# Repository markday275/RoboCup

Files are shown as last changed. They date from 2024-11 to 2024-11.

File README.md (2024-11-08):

# RoboCup - Third Place 2024

Welcome to the RoboCup Project repository! This project was designed and competed in the annual RoboCup competition for University of Canterbury third Yr Mechatronics, securing a **third-place finish**. This repository aims to maintain a well-documented structure for future enhancements, iterations, and collaboration in autonomous robotics.

## Table of Contents
1. [Project Overview](#project-overview)
2. [CAD](#setup-instructions)
3. [Code Structure](#code-structure)
6. [License](#license)

---

### Project Overview
This project is built around a robot designed to compete in RoboCup. There are three reports within this git that outlines the Robot in detail CDR , DDR and Competition report. Recommended reading is the Competition report as it outlines what worked and did not work in the competition. 

The robot is controlled by a Teensy 4.0 microcontroller with an IO expansion board. The teensy has 40 pins but 24 in the given configuration. Having a IO expander allows for the additional IO to be plugged in and multiplexed to. It also allows for standard connector types, serial, digital, i2c etc.
The code is developed and built in VS code as a platformIO project. This allows for greater functionality as the code written is C++ not Arduino C++. 

### CAD 
The robot has been designed to maximise simplicity and reliability. 
It uses sensors to gather information from the world. From this information it moves throughout area to gather weights and returns them to base.
To do this the robot must have primary motion system, the system implemented is a ‘tank drive’ system. The robot has ToF sensors that return distances from walls and obstacles which allow it to navigate throughout the area. 
The robot uses ultrasound sensors to identify all weights, it then uses the navigation system to rotate and drive towards the weight. The weight is collected then is kept on board with a “sheep gate” system using an inductive proximity sensor and servo. The inductive proximity sensor determines if the weight is a target or dummy. The robot then continues forward searching for more weights until it holds 3 on board where it returns home. 

See CAD for solidworks parts and refer to assembly to complete design

### Code Structure

The robot is controlled by a Teensy 4.0 microcontroller with an IO expansion board. The teensy has 40 pins but 24 in the given configuration. Having a IO expander allows for the additional IO to be plugged in and multiplexed to. It also allows for standard connector types, serial, digital, i2c etc.
The code is developed and built in VS code as a platformIO project. This allows for greater functionality as the code written is C++ not Arduino C++. 

The code is broken up into modules:
-	main.cpp: task scheduler set up and run. 
-	finite_state_machine.cpp: all states and logic to switch between them.
-	return_to_base.cpp: calculates where home is, if home and return home.
-	weight_collection.cpp: detects weights and functions to pick weight up.
-	smartmove.cpp: moves the robot based on sensors, move while avoiding walls etc.
-	motors.cpp: call to set motor/actuators values. 
-	sensors.cpp: takes in data from sensors.

### License
This project is licensed under the MIT License. See LICENSE for more details.

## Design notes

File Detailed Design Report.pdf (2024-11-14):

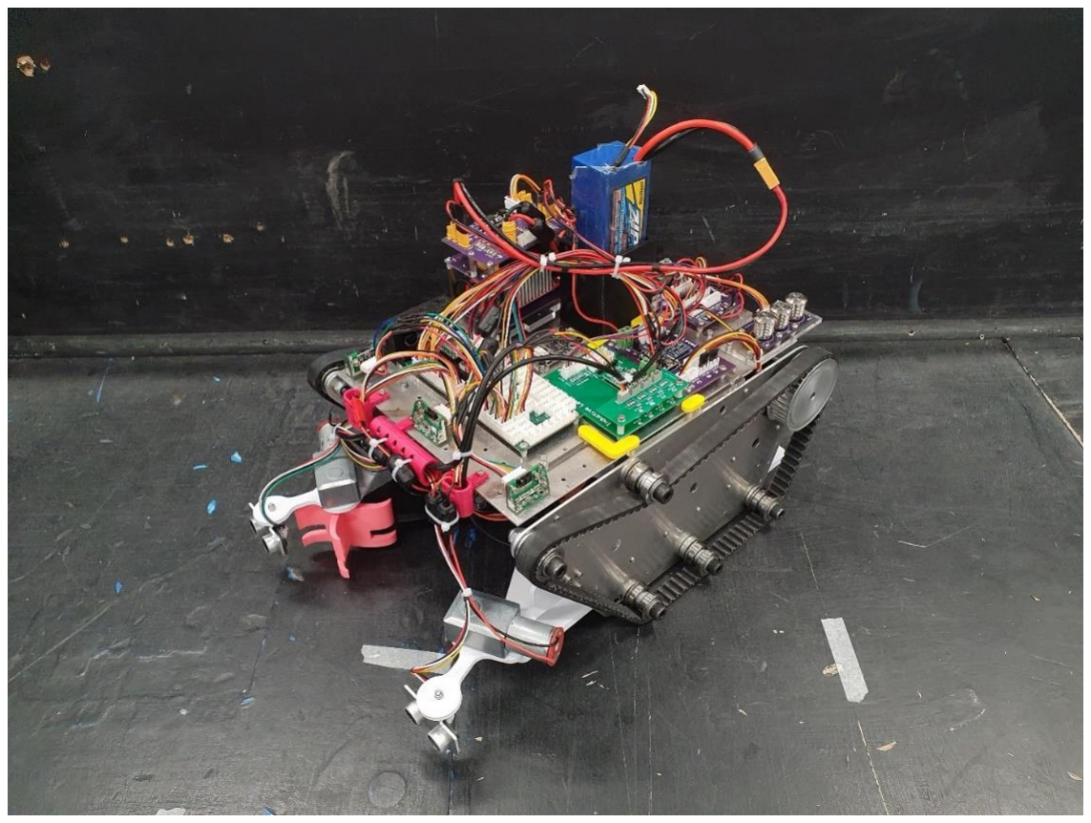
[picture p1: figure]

# Detailed Design Report

# ENMT301 09/09/24 Group 4

# Mark day

# Kieran James

# Jack Willson

i

## Executive Summary

To achieve desired outcomes the robot is divided into subsystem.

- Chassis and Drivetrain
- Target Detection
- Target Collection
- Navigation

The robot used a tank drive, drivetrain with the original gear. This fell short of the robot’s speed requirement 0.5 m/s. The actual speed achieved was 0.33 m/s. the chassis and drivetrain also produced a drift of -12%. Custom gears or software bias could improve speed and correct drift.

The target detection uses ToF and ultrasound sensors. A Boolean logic system detects targets and reduces noise with a moving average filter. This was tested using a best of 20 system by placing weights and recording the how successful the detection was. The target detection could be improved by consider replacing ultrasound sensors with more reliable ToF sensors.

The target collection uses a funnel and tray system that replaced the original combine harvester design. Weights are sorted based on material using an inductive proximity sensor and an IR sensor. The new tray system is reliable but does not meet the requirement for collecting weights in any orientation. Removing the combine motors could reduce weight and simplify the robot.

The robot navigation system works by detecting walls with ToF sensors and stores then position using odometry and gyro data. The system works inconsistently, with the robot failing to return home in three out of five runs. Additional ToF sensors and acceleration data from the IMU could enhance reliability.

An FTA was used to identify key components and likely causes of faults. From the FTA, Simplicity was prioritized to reduce risk, especially by replacing moving parts with static guides. The wiring was optimized for reliability, and code was modularized for flexibility. The gate was made from alloy to improve durability.

ii

## Table of Contents

## 1. Introduction

This report will detail the design and manufacturing of the RoboCup robot. It will detail each subsystem of the robot. Each subsystem will be assessed against the requirement set up in the conceptual design report (CDR). The subsystems will also be tested in a results section to improve the robot and recommendations made where the robot fails to meet the requirements.

The goal of the robot is to move out from home base into an area with obstacles and weights placed throughout. The robot must collect weights and bring them home to score points. The area layout is unknown, and the robot must not have any communication from the user. This makes the task difficult. To achieve this the following subsystems have been implemented

- Chassis and Drivetrain
- Target Detection
- Target Collection
- Navigation

The robot target collection has been changed from the CDR. This was due to reliability issues. The detail of the change is explained in section 2.2.

## 2. Design Description

## 2.1 Overview

The robot has been designed to maximise simplicity and reliability. The current robot is shown in Figure 1.

It uses sensors to gather information from the world. From this information it moves throughout area to gather weights and returns them to base.

To do this the robot must have primary motion system, the system implemented is a ‘tank drive’ system. The robot has ToF sensors that return distances from walls and obstacles which allow it to navigate throughout the area.

The robot uses ultrasound sensors to identify all weights, it then uses the navigation system to rotate and drive towards the weight. The weight is collected then is kept on board with a “sheep gate” system using an inductive proximity sensor and servo. The inductive proximity sensor determines if the weight is a target or dummy. The robot then continues forward searching for more weights until it holds 3 on board where it returns home.

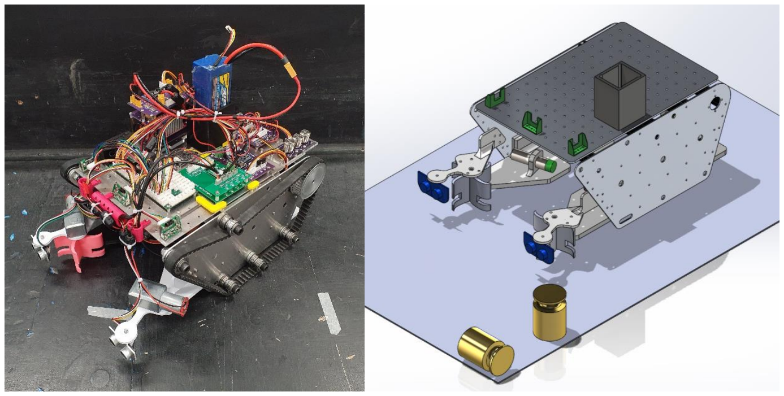
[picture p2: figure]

Figure 1: Group Four’s robot as of 08/09/24 (Left), CAD model (Right).

## 2.2 Chassis and Drivetrain

The chassis and drivetrain designs were taken from the CDR and used with minor modifications. The default chassis plates were used along with the standard configuration of tracks and bearings for the drivetrain (Figure 2) rather than printing new track sprockets as described in the CDR. The decision to use the standard sprocket was based on the fact the robot travelled at the desired speed with the alloy sprocket. The motors powering the tracks were 2x 28PA51G DC geared motors with built-in encoders. The motors were powered using a 2-channel DC motor driver and a PWM input. The extrusions were arranged to give the chassis sufficient stiffness and strength while allowing enough space at the front of the robot for the required weight collection components (Figure 3). Using the default chassis plates and extrusions also provided a significant amount of flexibility that was later found useful as the collection mechanism went through multiple further optimisations.

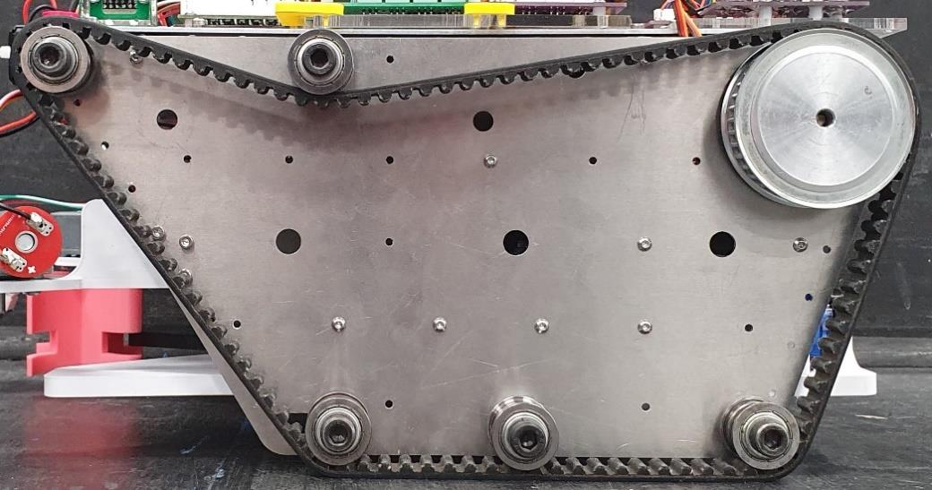
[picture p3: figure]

Figure 2: Chassis plate and drivetrain layout.

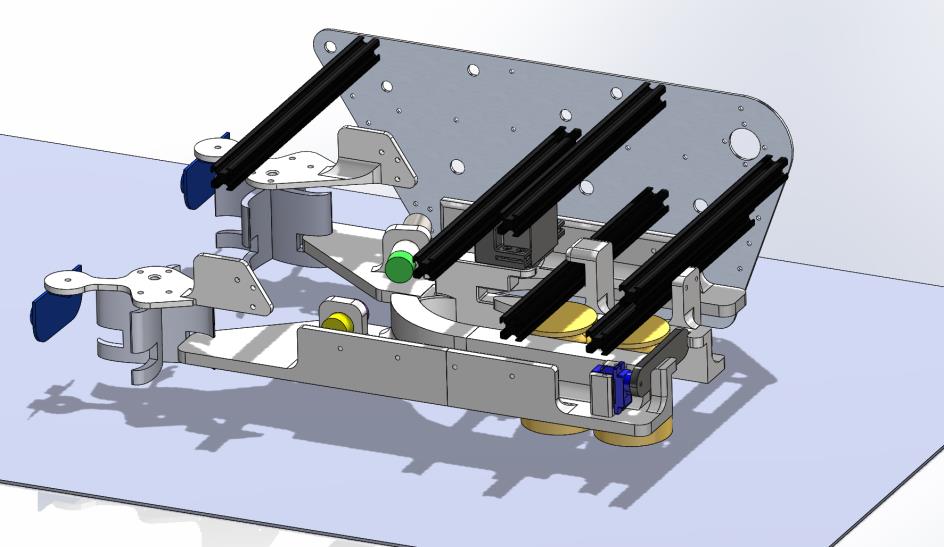
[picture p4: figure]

Figure 3: Arrangement of aluminium extrusions.

For mounting the electronics, the provided drilled plate was mounted to extrusions on the topside of the robot. This provided adequate space required for most of the supporting electrical circuits, the Teensy MCU and the battery (Figure 4). To fit some of the circuit boards, small brackets were printed as not all the boards had their own mounting holes. This made the electrical board more compact and discarded the need for a second mounting plate. The ultrasonic driver board and the second DC motor driver were attached to the underside of the electrical board for cable management and space. To help keep cables tidy, manageable and away from moving parts, cable organisers were printed and attached to the front. These also doubled as mounting points for cable ties.

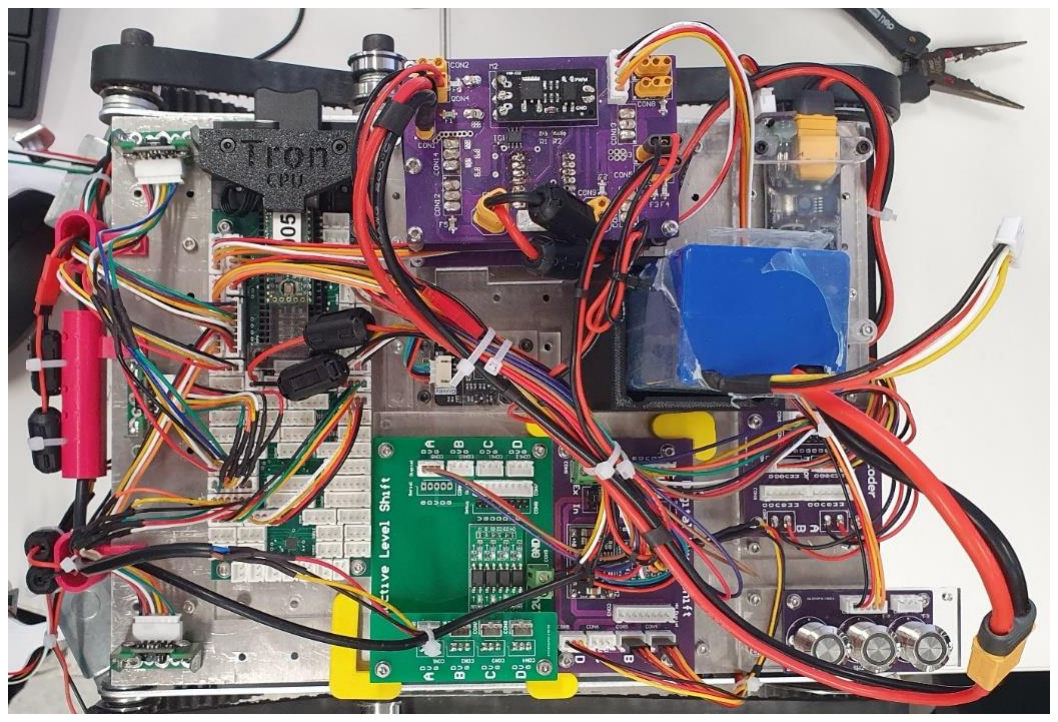
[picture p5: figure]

Figure 4: Electronics Plate

## 2.3 Target Detection

Time of Flight Sensors (VL530X) and ultrasound sensors (HC-SR04) are used for target detection. The TOF’s are mounted at the top of the chassis meaning they detect walls and other robots while being above the height of target weights. There are two ultrasound sensors placed lower to the ground at the front of the robot. In code a Boolean, “is_target_found”, is assigned a true value if the digital TOF read is larger than the digital ultrasound read. The TOF is likely to detect a wall while if the reading is the same for the ultrasounds, they must be detecting the same wall. Additionally, a moving average filter is applied to reduce noise, smoothing the output signals.

## 2.4 Target Collection

After the CDR was completed and the concept was selected, once the design process had begun it became apparent that the chosen design would be difficult to implement and manufacture. Further investigation also found some reliability issues around the ‘combine harvester’ design for collecting weights. One of which was difficulty directing the weight to a specific location to be examined if the weight is metallic or plastic. A solution to this was to have a tray that funnels weights into a channel (Figure 5). The technical drawing for the right-hand tray can be found in appendix C. The funnel would position the weight in the channel (without knocking the weight over) where a gate would then stop the weight in the channel next to an inductive proximity sensor.

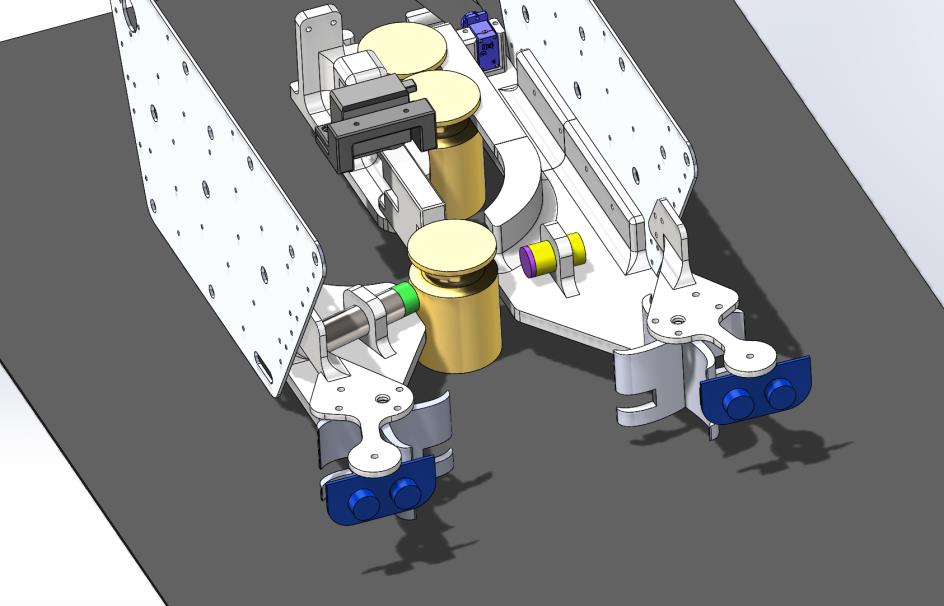
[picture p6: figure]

Figure 5: The trays make up the funnel, the channels and brackets for sensors.

The gate would then draft the weight to be kept or discarded depending on if it was metallic or not. Plastic weights are free to be discarded from the rear of the robot and target weights are directed into a closed off channel and held in the robot for the remainder of the round or until the robot travels to it’s home base. The holding bay (Figure 6) was designed to fit and carry three target weights of any weight. A separate servo with a gate prevents them from exiting the bay at the rear. The left-hand tray and the centre partition create the holding bay channel. The channel is designed to have a lip that fits into the slot of the weight preventing it from falling out the bottom of the robot.

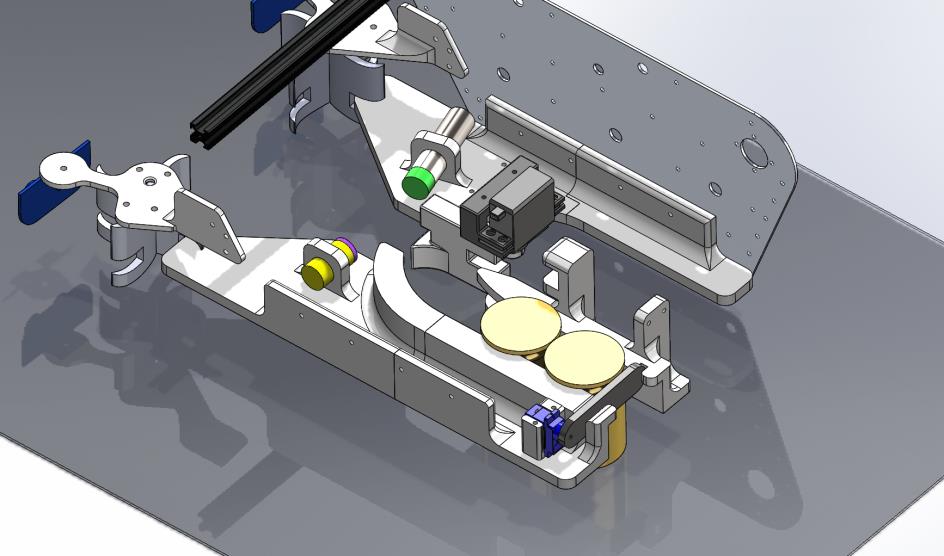
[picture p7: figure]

Figure 6: The weights are held upright and contained in the robot in the holding bay.

To keep parts of the original concept in the new design, the ‘combine harvester’ was remodelled into two vertical sweepers. The purpose of these were to increase the width of possible collection area by sweeping weights from a wider span into the funnel. Two DC geared right-angle motors are mounted to the two front brackets and drive the sweepers.

The gate has been specifically designed to be able to rotate 90 degrees into the holding bay (Figure 7). A technical drawing for the gate can be found in appendix C. This is so the gate can push the weights further down the channel to prevent a weight from travelling back out the front of the robot in the occasion that the robot must reverse. The hook in the gate also provides higher chance of gate pushing the weight into the holding bay rather than jamming against the weight. The gate is driven by a HX12K servo that can provide up to 9.4kg/cm of torque, which is adequate for pushing and holding up to three weights. The servo has a 3D printed bracket that is mounted to an extrusion, as seen in Figure 7 and 8.

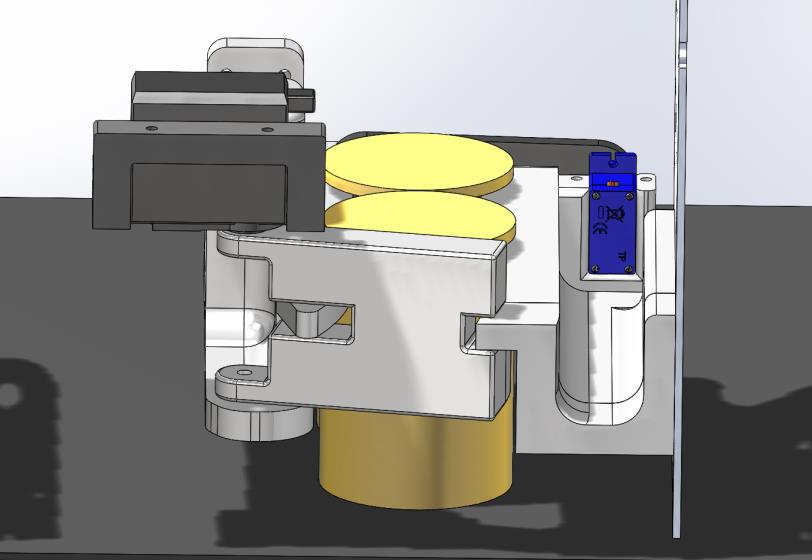
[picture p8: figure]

Figure 7: Gate securing two target weights in the holding bay.

To support the bottom of the gate a M4 cap screw is threaded into the bottom of the gate acting as a removable pin and the head of the bolt rotates in the centre partition. The reason for having a removable pin is so there is easy access to the cap screw holding the gate to the servo and so the partition can slide backwards to remove. The centre partition provides the necessary support to hold the target weights and creates one side of the holding bay. To mount the partition to the robot, a slot at the front fits over one extrusion and two bolts hold the rear to a second extrusion (Figure 8). The design allows for significantly simpler assemble as access to the front extrusion is limited and this results in a total of only 3 bolts holding the partition in. An advantage of mounting the servo and partition to the extrusions is the ability to adjust the width of the channel for fine tuning.

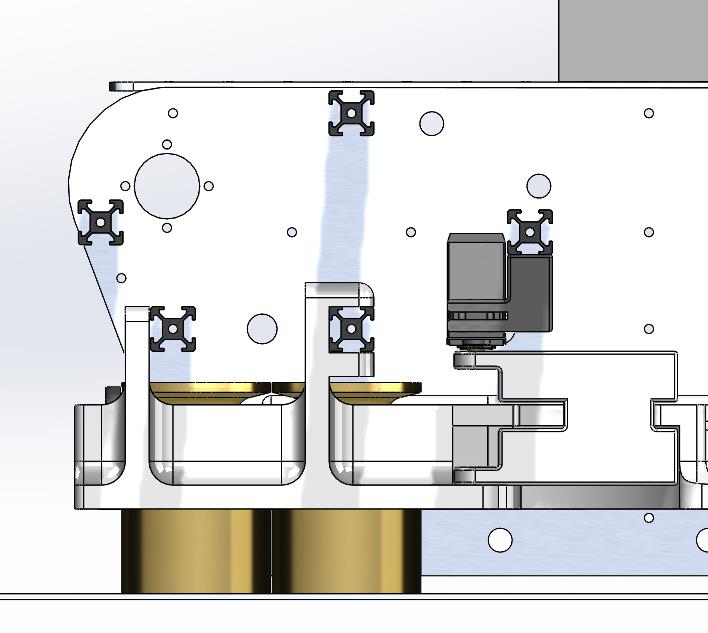
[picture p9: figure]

Figure 8: The centre partition mounted on two extrusions.

## 2.5 Navigation

The robot detects walls using three ToF sensors (VL53L1X). One centre sensor detecting walls in front of the robot and the other two at the front looking left and right to detect walls next to the robot.

From the data sheet the FoV of the ToF is 27 degrees. This means that the robot should be able to detect any obstacle in front of it at a distance of 450mm or greater as shown in Figure
9. The sensors can detect walls from 40 to 4000 mm.

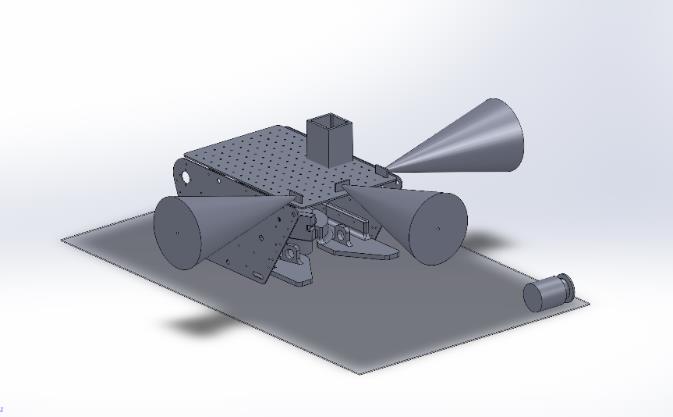
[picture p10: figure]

Figure 9: ToF Field of View

The robot searches for weights based moving into the most free space. The robot moves forwards until it detects a wall. Once detected it uses the left and right sensors to determine which direction has walls further away and turn towards that direction. Moves until the it detects a wall and repeats the process.

The robot navigates by remembering where it is and certain locations it has been. It does this by storing an x, y position where 0,0 is home base but also it can then store approximate position of obstacles and weights as it comes across them. The x, y positions are calculated by combining the angle from the gyro and the odometry recorded from the encoder.

To move the robot to a given x, y position the function “MoveTo” can be called. This function turns the robot until it is facing the correct heading. From there it will start to move forward till it reaches a wall. Once there is a wall or obstacle in its way it will turn towards the most free space and move forwards. Once it no longer sees the obstacle it will turn back towards the given x, y heading and move forward again repeating the process if another wall is encountered.

## 2.6 Software Design

The robot is controlled by a Teensy 4.0 microcontroller with an IO expansion board. The teensy has 40 pins but 24 in the given configuration. Having a IO expander allows for the additional IO to be plugged in and multiplexed to. It also allows for standard connector types, serial, digital, i2c etc.

The code is developed and built in VS code as a platformIO project. This allows for greater functionality as the code written is C++ not Arduino C++.

The code is broken up into modules:

- main.cpp: task scheduler set up and run.
- finite_state_machine.cpp: all states and logic to switch between them.
- return_to_base.cpp: calculates where home is, if home and return home.
- weight_collection.cpp: detects weights and functions to pick weight up.
- smartmove.cpp: moves the robot based on sensors, move while avoiding walls etc.
- motors.cpp: call to set motor/actuators values.
- sensors.cpp: takes in data from sensors.

The module dependency tree is shown in Figure 10.

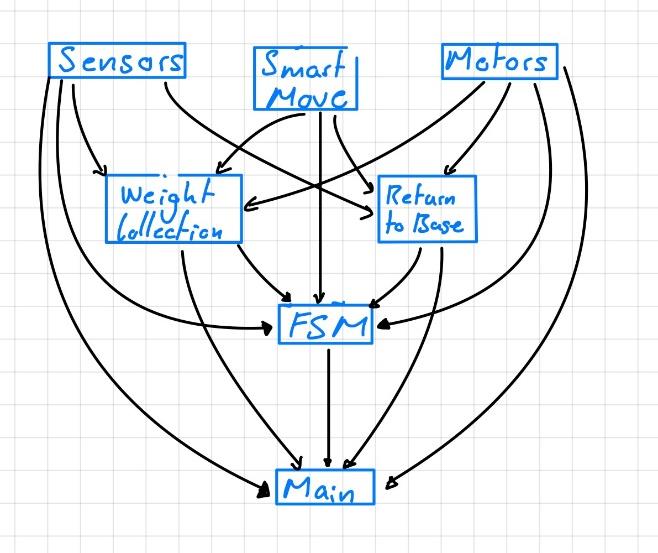
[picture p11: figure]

Figure 10: Module Dependency Tree

The modules are designed such that there is low level logic which only deal with getting inputs and outputs from the real world. Moving down the tree more algorithms and less input and output is found in the modules. The modules are based on subcomponents. This means algorithms can be changed without needing to change the entire code base.

The Finite State Machine is the powerhouse of the program. It sets what functionally is allowed and ensures that each task is carrying out in the order it should be. Figure 11 shows the states and how they interact with each other.

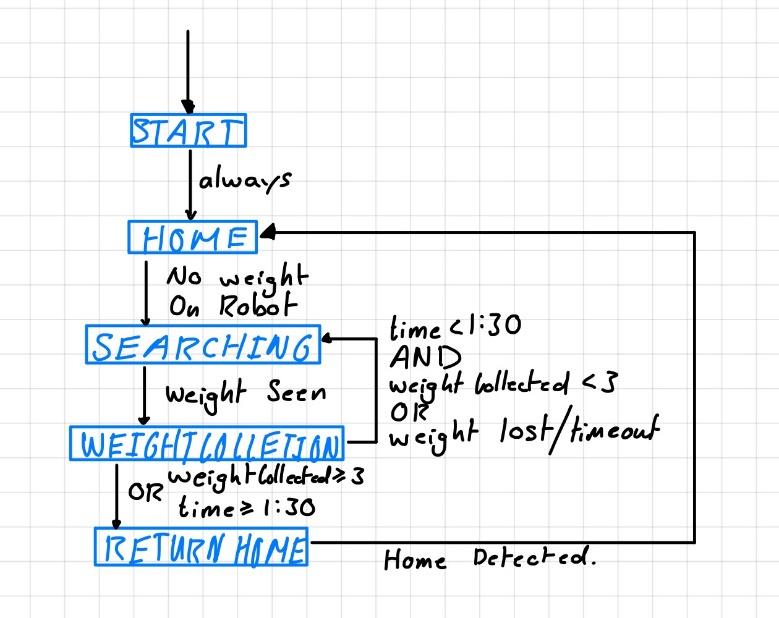
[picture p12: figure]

Figure 11: State Machine Diagram

- Start State: ensures all actuators are in position.
- Home State: unloads weights.
- Searching State: moves the robot based on a most free space algorithm.
- Weight collection State: move towards weight and determines fakes.
- Return Home State: returns the robot to home avoiding obstacles.

## 3. Results

## 3.1 Chassis and Drivetrain

The taking the average speed of 3 runs the speed of the robot was determined to be 0.32 m/s this falls short of the required speed 0.5 from requirement 2.4.

Another factor measured was the motor drift this was not explicated included in the requirements but affects the ability of the to effectively drive. The drift was measured to be -12% or in other words, the robot would move to the left 120mm every meter moved.

## 3.2 Target Detection

The ultrasounds must be tested to see if they contribute to the design requirement 1.8. If the Robot detects a weight in the arena, it shall be able to move towards it successfully. To test the ultrasound sensors, the robot was placed in the practice arena with a target weight placed in its view within 15 degrees of either side. The serial monitor was used to determine if the robot had successfully detected the weight. The target weight was placed at different positions including both near and far with far weights being placed within the sensor's detection limit of 400cm. Tests were also completed with multiple weights in view with a successful test being decided if the robot identifies the closest weight and correctly moves towards this weight. Table 1 shows the score for each category being the number of times out of 20 tests a successful detection occurs.

Table 1: Ultrasound Detection Test

TEST | NEAR
| TARGET | FAR TARGET | NEAR
| | | TARGETS | FAR
| | | | TARGETS
1 ULTRASOUND | 16 | 12 | 12 | 10
2 ULTRASOUNDS | 20 | 16 | 17 | 16
3 ULTRASOUNDS | 20 | 15 | 4 | 18
4 ULTRASOUNDS | 20 | 19 | 16 | 17

The results show a reduction in accuracy when detecting multiple weights as more ultrasound sensors are added. This is likely due to the complexity of the code required as more sensors are added. The near target was the most accurate however with multiple targets weights this accuracy dropped off significantly. To further increase the accuracy there should be further coding improvements.

## 3.3 Target Collection

The new changes in the weight collection mechanism resulted in failure of one the requirement proposed in the CDR. The tray system does not allow weights to be collected in any orientation as laid out in requirement 1.9. The tray was designed to act low on the weight to prevent toppling, this proved useful as driving towards a weight was tested 10 times and not once was a weight tipped over. After some fine adjustments of the position of the inductive proximity and digital IR sensor, the robot was able to distinguish accurately when a weight was in position to be tested. The inductive proximity then successfully recognised if the weight is metallic or plastic for 100% of the 10 tests. These tests were carried out by driving the robot towards the weight with external weight detection turned off.

Separate testing was used when examining the effectiveness of the channel and holding bay. The gate was set in the open position for the holding bay and weights were placed in the channel as if they were detected as metallic. The robot would then drive forward, and the weight would slide into the holding bay. This was successful 9 of 10 times where one time the weight got stuck at the intersection of the gate and the partition. This is easily resolved by closing the gate towards the holding bay and the weight would be pushed into the holding bay. The release mechanism was tested with a full holding bay and opening the rear gate and driving forward. All three weights were deposited out the robot.

## 3.4 Navigation

The navigation system works well when it works and when it doesn’t it causes it to get stuck on obstacles without being able to recover or can no longer find home which fails the requirement of 2.3 for the concept report. It never hit any walls.

Table 2: Navigation Results

RUN | OBSTACLES
| HIT | STUCK | QUADRANTS
| | | VISITED | HOME
1 | 2 | 0 | 4 | 1
2 | 3 | 0 | 4 | 0
3 | 2 | 1 | 3 | 0
4 | 4 | 2 | 2 | 0
5 | 3 | 0 | 4 | 1

Table 2 shows the performance of the robot moving from home into the field then back to home after 60 seconds. It should be noted that it only made it home twice out of 5 runs.

It was observed that if the robot hit obstacles or gets stuck the wheels would spin without it going anywhere. This would mean that the robot thinks it has travelled without doing so and hence its map no longer reflects reality and cannot find real home again.

Two main factors that were observed to cause the poor performance. One is the front Tof missing obstacles as shown in Figure 12.

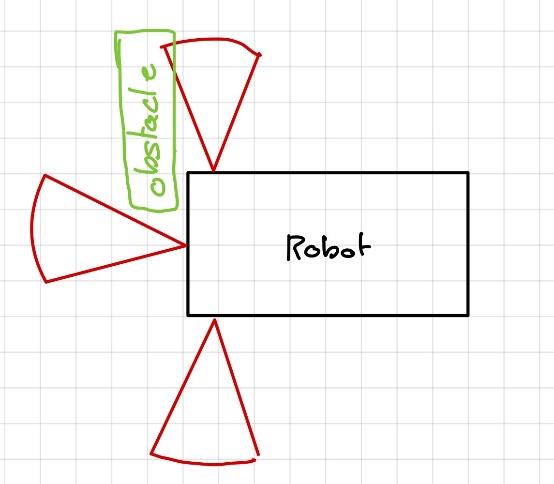
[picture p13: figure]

Figure 12: Obstacle Missed Diagram

The other lesser cause was the motor drift causing the robot to always turn left when its meant to go forward. Although this shouldn’t cause the navigation system to fail. It causes it to stop redirect itself and then start again.

## 3.5 Cost Analysis

We used 386 grams of PLA for 3D printing, but 300 grams of PLA was included in the budget. This resulted in an extra cost in PLA of $4.30 NZD. All parts designed were manufactured using 3D print except the main gate, this will be milled out of aluminium for strength as it provides a stronger mounting point to the servo. The aluminium has an approximate extra cost of $11.40 NZD. We used 1 extra ToF sensor (long-range) than what was provided, this had an extra cost of $10 NZD. Everything else is included in the budget. The total additional cost of the robot came out to $25.70 NZD which is well within the additional costs budget of $50. A full bill of materials can be found in appendix 7.1.

## 3.6 Requirement Analysis

Table 3 shows what requirement has been meet. Explanation of fail and recommendation can be found in their respective result/design sub system or further development. Stars refer to inconsistency.

Table 3: Requirements Specification

Functional +
Performance
Requirements
Description | Pass/fail
1.1 | The Robot shall be able to recognise if it is at ‘home’ or in the playing arena | PASS
1.2 | The Robot shall be able to distinguish between its home and its opponent’s home. | PASS
1.3 | If the Robot is positioned at its home and contains weights, it must place the weights on home. | PASS
1.4 | The Robot should return home once it contains three weights. | PASS
1.5 | The Robot shall be able to recognise walls in relation to itself. | PASS*
1.6 | The Robot shall be able to traverse all the following obstacles: | PASS
1.6.1 | Speedbumps of minimum 25mm high. | PASS
1.6.2 | Ramps of minimum 100mm high and 30% gradient. | PASS
1.7 | The Robot shall be no greater than 400 mm wide. | PASS
1.8 | If the Robot detects a weight in the arena, it shall be able to move towards it successfully. | PASS
1.9 | The Robot shall be able to collect weights placed in any orientation. | FAIL
1.10 | The Robot shall only collect weights in the playing arena. | PASS
1.11 | The robot should not collect fake weights. | PASS
1.12 | The robot shall be able to collect weights against arena walls and obstacles. | PASS
1.13 | Once identified The Robot should not interact with a dummy weight consecutively. | PASS
1.14 | The Robot shall cash in weights before the end of the round. | PASS
2.1 | The Robots battery shall last for at minimum, 2 minutes. | PASS
2.2 | The Robot shall be able to pick up a weight once it enters a picking up mode within 5 seconds. | PASS
2.3 | The Robot shall not be stuck on in a subsection of the arena for more than 20 seconds | FAIL*
2.4 | The Robot shall be able to move at least 0.5 m/s whilst fully loaded. | FAIL

## 4. FTA

In general from the FTA, it was decided that all subcomponents should be kept as simple as possible. For example, the moving combine was replaced with a guide rail system and moved to a less important sub system. This was due the added risks involved with moving parts.

From the FTA a common fault was wiring issues as this could lead to failure of the drivetrain, weight collection, and detection system. Due to this the importance of designing for reliability in the wiring system, Figure 13 was prioritised.

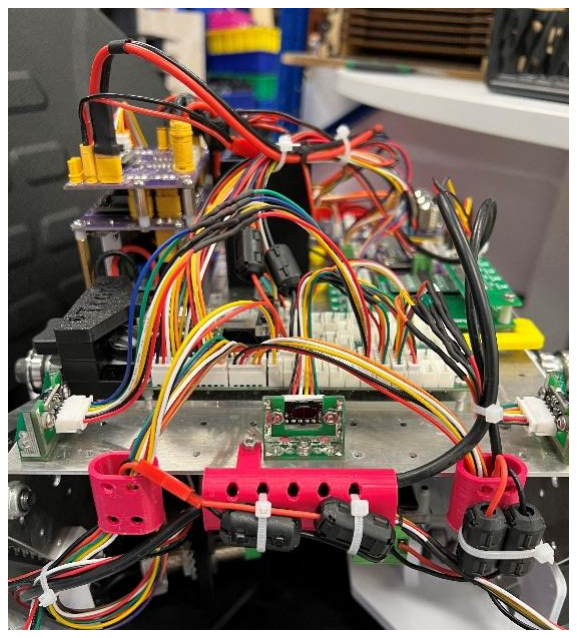
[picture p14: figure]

Figure 13: Photo of Wiring System

The Number of wires were minimised, and tip tied together. This increased the manufacturing time but also increased the reliability. Wire conduits were made to protect the wires from hard edges and organise wires. Connections were kept as close as possible, and wires shorten where they could be.

The code was determined from the FTA to be a common fault. Due to this coding style and naming standards were implemented. The code was modularised such that the logic/computation and real-world inputs/outputs were separated. This allows the code to be more reliable to changes. Camel case naming was implemented to improve readability.

From the FTA poor collection design was a critical fault. Due to this the gate will be made out of alloy. Doing this decreases the chance of the gate breaking and improves the reliability when other robots collide with it.

## 5. Evaluation / Further Development

## 5.1 Drivetrain

The drive train could stand to have a custom gear. This would allow for a higher ratio gearing and thus a faster speed meeting requirement 2.4. This would also allow for an opportunity to address drift as a bias could be put on one gear. Otherwise, a software bias can be used to reduce drift.

## 5.2 Navigation

Increasing the number of ToF sensors on the front of the robot to at least two and then taking the minimum value between them and considering that the front ToF sensor value. This would eliminate the robot clipping obstacles and meet requirement 2.3.

Adding the acceleration data from the imu into the navigation system could improve the reliability. Normally acceleration data is integrated for displacement, and this could replace the need for encoders that miss interpret information when the wheels slip. This was found to be a suboptimal solution due to sensor drift. Even though there are methods to eliminate drift. A more interesting solution would be to use the imu to detect if an obstacle has been struck (a large spike in acceleration) and then throw away encoder values whilst stuck or make the robot back up.

## 5.3 Weight Detection

The ultrasound sensors for target detection work fine but could be improved. An issue that was discovered was that the ultrasound sensors were taking a very long time to process when objects are further than 4m away. This was causing the CPU to hang and cause unexpected behaviour. This may not be an issue in the arena as object would be within 4m most of the round, but it is possible. One idea is to use TOF sensors instead of ultrasounds as these have been very simple to implement so far. Further testing would be required to determine if these would be a successful alternative.

## 5.3 Weight Collection

The combine motors could be removed entirely as the effectiveness of them have been reduced as the weight collection system includes a 3D printed “funnel” to collect weights. The combine and motors add unnecessary weight and overcomplicates the robot while also not improving the weight collection a significant amount. Power consumption is not currently an issue for the robot however removing the dc motors running the combines would reduce a lot of weight from the robot while also halving the number of DC motors running reducing power consumption.

## 6. Contribution statement

## 6.1 Mark

For the robot, I contributed to the software design, moving it to a platformIO project and creating modules. I implemented the navigation system in code and electronically. I also contributed to the electronic layout and cable management. I assisted in the development of the target collection combine wheels. For the report I wrote: The design and result for the navigation, the effect of FTA on design, design of software and the summary.

## 6.2 Kieran

I contributed mostly to the coding of the target weight detection and collection. Designed CAD models for a few minor parts. I also assisted in the setting up and testing of sensors such as time of flight, ultrasound, colour and inductive proximity. For the report I completed the target detection overview and FTA as well as the results section for target detection.

## 6.3 Jack

I have contributed to the design, manufacture and assembly of the weight collection system including the trays, partition, gates, servo mounts. I transferred all the designs to CAD models except the ‘combine’ wheels and brackets. I created the technical drawings for two of the 3D printed parts and assembled the entire robot in CAD. I created the circuit board brackets and contributed to the electrical layout. I contributed to the chassis, drivetrain and weight collection sections of the report, as well as the costing section and bill of materials.

## 7. Appendix

### A. Bill of Materials

Part Description | Part Number | Cost per Unit ($ NZD) | Quantity
Teensy 4.0 MCU | TEENSY40 | 23.80 | 1
Chassis Plates | | | 2
Robot tracks | 880-8M | | 2
Drive Pulley | | | 2
Track Bearings | | | 10
Electrical Plate | | | 1
Aluminium Ex. 223.5mm | | | 6
Digital Level Shift | | | 1
Inductive Level Shift | | | 1
Encoder Board | | | 1
DC Motor Driver | | | 2
Power Supply Module | | | 1
Power Buttons | | | 1
Colour Sensor | TCS34725 | 14.00 | 1
Ultrasound Board | | 1.00 | 1
Ultrasound Sensors | HC-SR04 | 1.80 | 2
TOF sensor (Long) | VL53L1XV2 | 10.00 | 3
IMU Sensor | SEN0253 | 36.00 | 1
Inductive Proximity | LJ18A | 25.00 | 1
Digital IR Sensor | SEN0019 | 6.00 | 1
Servo | HX12K | 14.00 | 1
Servo | SG90 | 2.50 | 1
DC Motor with encoder | 28PA51G | 70.00 | 2
DC Motor 200RPM | SKU505979 | 15.00 | 2
Aluminium Billet | | $11.40 per 100x100x15mm | 75x45x15mm
PLA | | 0.05 per g | 386 g

### B. CAD Photos

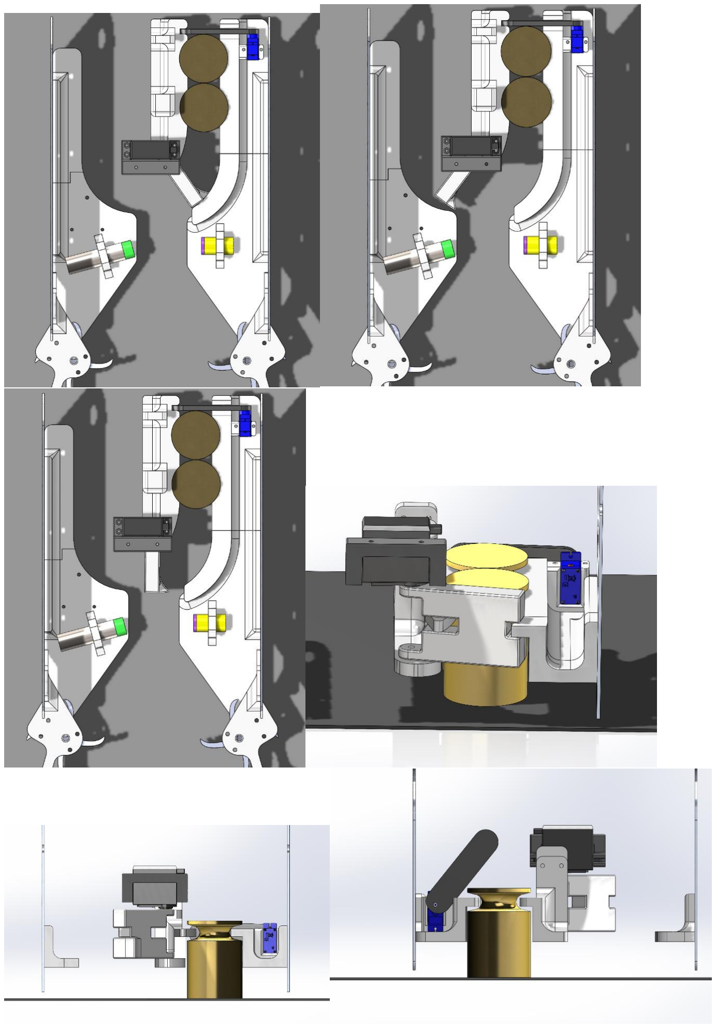
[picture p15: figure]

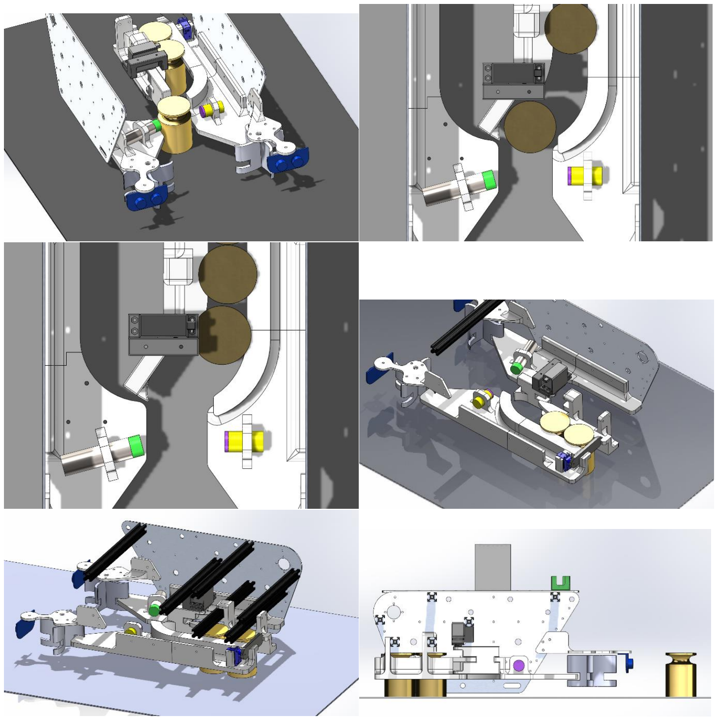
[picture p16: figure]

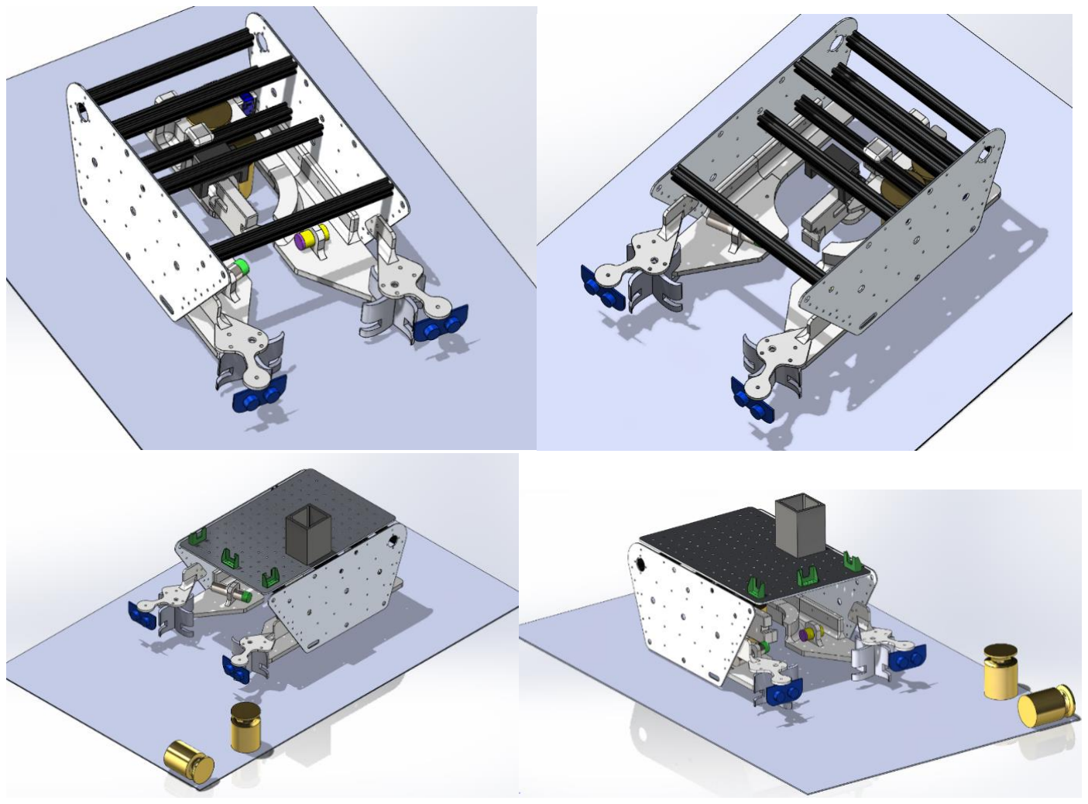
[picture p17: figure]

### C. Engineering Drawings (Right-hand Tray, Gate)

### D. Fault Tree Analysis

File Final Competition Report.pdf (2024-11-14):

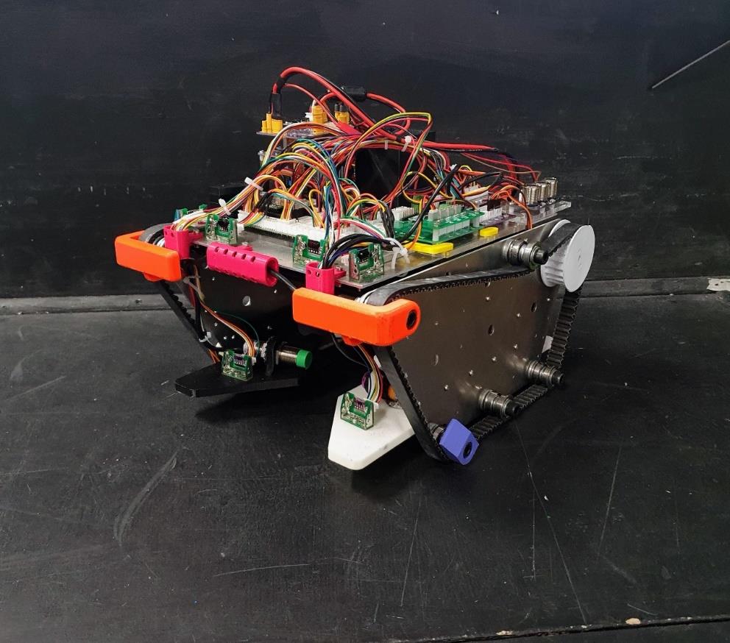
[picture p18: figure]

# Design Evaluation Report

# ENMT301 - 18/10/24

# Group 4

# Mark day

# Kieran James

# Jack Willson

ii

# Executive Summary

This report outlines the design, development, and competition performance of Group 4's robot built for the Robocup Competition. The main goal of the robot's design was to effectively navigate the arena, detecting and collecting target weights, while avoiding dummy weights and obstacles. The robot's design features included a tank drive system, a rail-based collection mechanism, and a navigation system that includes multiple time of flight (TOF) sensors for object detection.

Since the DDR report, there changes were made to subsystems. Changes to the drivetrain included the addition of front corner bumpers, lower track slides, and a custom 3D-printed main drive pulley. The target detection system was upgraded from ultrasonic sensors to TOF sensors, which significantly increased accuracy and speed in detecting weights, while the target collection mechanism was simplified.

In the Robocup competition, Group 4’s robot was effective as it consistently collected weights in multiple rounds, securing 3rd place overall. The robot’s strategy focused on quickly moving off its home base to collect target weights before the other teams, maximising the potential score. The robot's navigation system, which employed a combination of motor encoders and an IMU, enabled it to traverse the arena and return to its home base with minimal error.

One main issue was the weight disposal system, which struggled to consistently deposit weights within the home base, resulting in lost points during critical rounds. The robot also had difficulties when dealing with weights that were not in an upright position, as its collection mechanism was not able to handle tipped-over weights. Minor issues with the drivetrain occasionally caused the robot to get stuck on obstacles like poles and ramps, despite the improvements made during testing.

Cost analysis revealed that the robot remained within budget, with the total cost of additional components amounting to $43.20 NZD, compared to the allocated budget of $50. A full breakdown of the budget and bill of materials is provided in the appendix of the report.

Overall, the robot was deemed to be fit for purpose, successfully meeting most of its design requirements and performing competitively against other teams. The areas for future improvement identified in this report include developing a more reliable weight disposal mechanism, enhancing the robot’s ability to handle tipped-over weights, and refining the navigation strategy to prevent it from getting stuck on obstacles. Addressing these issues would significantly increase the robot's reliability and performance in future competitions.

iii

# Table of Contents

# 1. Introduction

This report will discuss the Robocop competition and more precisely discuss Group 4 robot’s performance in the competition with reference to robot design, game strategy and competitors.

Robocup is a competition between teams to build, construct and compete robots in one-on-one competitions. The competition consists of each team starting on a home base, then moving off into the playing field. In the field there are target weights, dummy weights, obstacles, poles and ramps. To score robots must collect target weights and score double if they get the weight back home. Dummy weights minus points if on board robots. There are two reports before this, Conceptual Design Report CDR which discuss different strategies and potential designs, and Detail Design Report DDR which discuss in detail Group 4s implementation of strategy and design.

# 2. Design Description

## 2.1 Overview

The design of the robot had some key improvements made to major components that would lead to the success of the robot in the competition (Figure 1). Changes were made to sub-systems such as the drivetrain, chassis, detection, collection and navigation. These changes were all made after the design report as the robot was going through extensive testing to iron out any flaws in the on-board systems. Some of these changes would occur between rounds of the competition due to issues occurring in rounds that had not been discovered yet. The results of these improvements would yield a robot that has greater reliability and simplicity which aligns with our objective from the detailed design report (DDR).

The final robot for the competition was a tank drive robot, navigated by moving into open spaces, collected weights using a rail system and detected weights with TOFs.

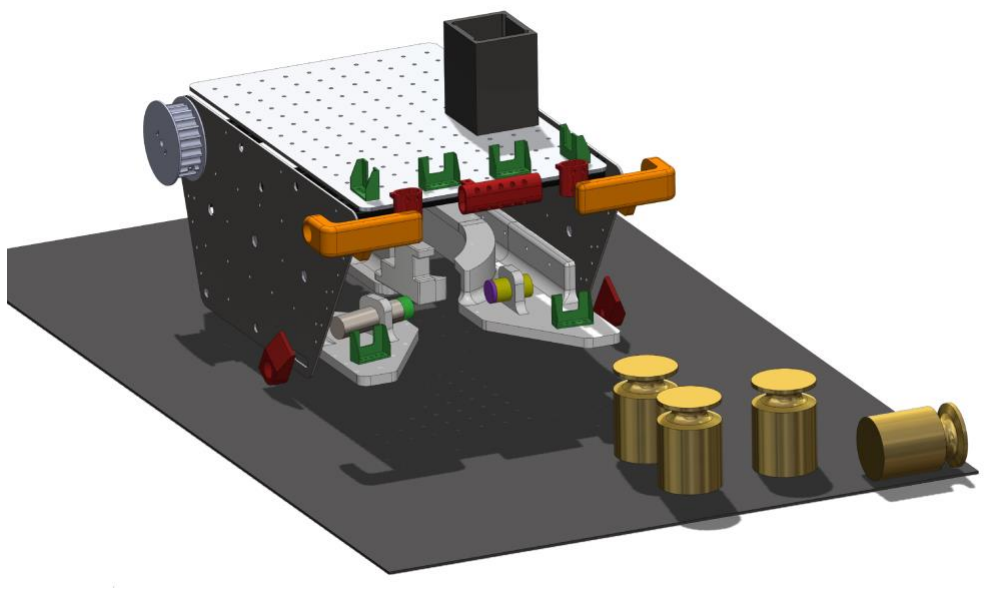
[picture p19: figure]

Figure 1: Group 4 finalised robot design.

## 2.2 Chassis and Drivetrain

The chassis and drivetrain of the robot made use of many components supplied in the Robocop kit. The robot chassis was kept simple by using the chassis plates, the standard geared DC motors with encoders, belts and bearings, and the black extrusions. All the major electronics were housed on the supplied alloy plate as the number of electronic components was kept to a minimum. By using supplied components for the drivetrain and chassis, this proved to decrease the time spent in design stage and allowed more time to be put into testing and development of other sub-systems of the robot. The function of the default components worked well for most parts of the requirements, but was not perfect, and minor changes had to be made to get the drivetrain running as smoothly as possible.

Three key improvements were made to the chassis and drivetrain; two were the addition of front corner bumpers and lower track slides and the third was a modification to the main drive pulley. The front bumpers (orange) seen in Figure 2, were an important step to allowing the robot to navigate the entire arena autonomously without getting stuck on any obstacle. This was important to achieve as one of the requirements from both earlier reports was that the robot shall not get stuck in a subsection of the arena (requirement 2.3) which includes getting stuck on obstacles. There were many occasions when the robot would approach a skinny vertical obstacle, such as the end of a wall, that was out of the field of view (FOV) of all the top time of flight (TOF) sensors. The obstacle would get caught in the section between the track and the cable management loop and the robot would continue to drive forward. This issue would lead the robot to violate requirement 1.4, the ability to drive home with weights, and 1.5, the robot shall be able to recognise walls in relation to itself. An important issue about getting stuck on obstacles is that most of the time it caused the tracks to slip on the ground, and because our navigation system was based on the encoder output from the motors, the virtual home position calculated on the robot would drift away from true home, therefore violating 1.4. The aim for the design of the bumpers was that if the robot were to hit the corner of an obstacle, the robot would slide off the obstacle as fast as possible and direct the obstacle to the closest TOF sensor so the navigation software could react. By doing this, it would minimise the amount of track slip and help towards achieving all the requirements and increasing reliability.

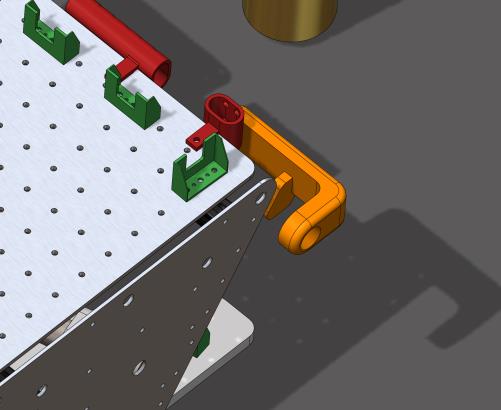
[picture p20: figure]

Figure 2: CAD assembly of the bumpers.

The lower track slides (Figure 3) were an addition made after the first round of the competition. A pole in the arena got caught on the cap screw holding the lower front track bearing causing the robot to rotate continuously around the pole. This caused similar requirement issues as mentioned above as the tracks slip and the robot was not able to navigate away from the obstacle. The slides provided an angled edge for the pole to slide off and the robot would be free to move on. Testing proved them to be successful and this issue never occurred again.

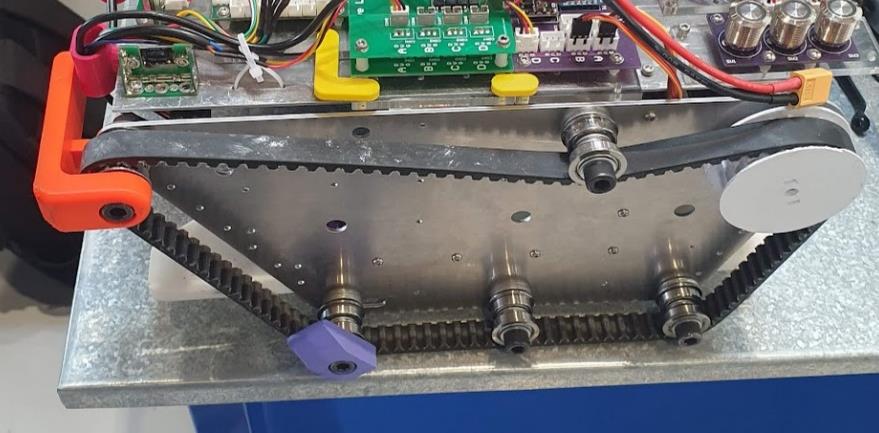
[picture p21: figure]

Figure 3: Implemented lower track slides (purple) and new drive pulley (white).

The third improvement was the 3D printed main drive pulleys (Figure 3) which included a better tooth design for the belts used. A common issue with the old aluminium pulleys was that the belts would slip on the pulley as the teeth were not the correct size for the belts. This only occurred when the robot was navigating bumps in the arena which applied more load on the pulleys. The slippage in the belts caused similar issues with virtual home drift so therefore required rectification. An IMU was onboard the robot but the absolute position from the IMU proved to have far less accuracy than when the encoders were reading correctly, so it was chosen to fix the slippage with all three improvements rather than changing the positioning system. This improvement was mentioned as further development in the DDR and was implemented successfully.

## 2.3 Target Collection

The collection system was designed to be as simple as possible while still having a high success rate. The weights are scanned for by the two lower TOF sensors, where the robot would then drive towards the weight until the weight is funnelled by the trays into the centre and stopped by the centre positioned gate. The weights are simply drafted by a 3D printed gate driven by a servo after they have been analysed as a target by an IR distance sensor and an inductive proximity sensor. The gate would move to either side and allow the weight to go to its designated position. If the weight was a dummy, then the robot leaves it to be expelled out the back, or a target is swept into the holding bay and up the rails to be lifted off the ground. The same rear gate and servo from the DDR were used at the rear of the holding bay to keep weights contained on the robot.

Two major changes were made to the collection system after the DDR, these were removing the combine harvester wheels and ultrasonic sensors and raising the holding bay rails so that the weights were lifted off the ground while contained on the robot. The final underbody of the robot can be seen in Figure 4. Removing the combines was mentioned as further development in the DDR due to their effectiveness, power consumption and complexity of electronics. They were found to be futile when collecting weights as they spanned the same distance as the funnel and making them wider would only cause them to catch on obstacles in the arena. Removing them made the robot as a whole more simple and allow focus to be put onto target detection and software.

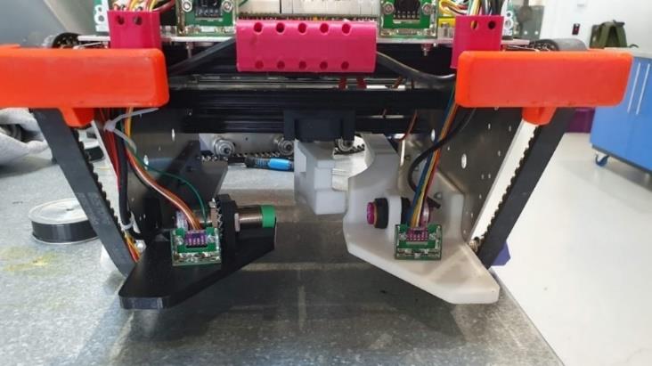
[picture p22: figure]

Figure 4: New TOF sensors and collection trays installed on the robot.

The other major change to lift the weights off the ground came from the robot’s inability to drive when fully loaded (requirement 2.4). This occurred multiple times during testing as the weights in the holding bay dragging on the ground would catch on small inconsistencies in the arena floor bringing the robot to a halt. The rails were adjusted upwards with a small incline at the front to lift the weights ~8mm off the ground (Figure 5). This was just enough to clear all the bumps on the ground including the rails around the home bases in the arena and allowed the robot to drive freely and satisfy requirement 2.4. The downfall to this solution was that there weas no easy was to dispose the target weights from the robot into the home base. A solution to this was implemented in code where the robot would open the gate when home and drive forward abruptly, shunting the weights towards the back, slow down, reverse and abruptly drive forward again. This solution was used in the final design and through testing was found to be simple and effective.

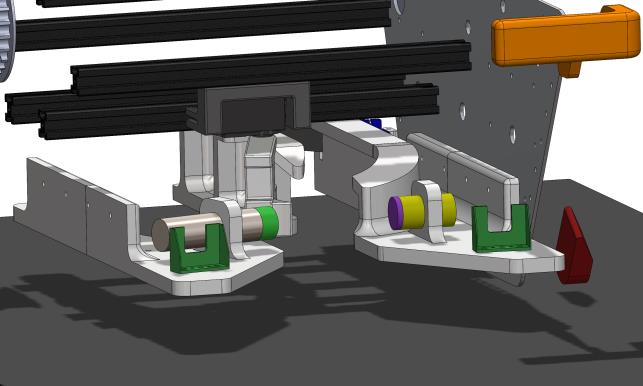
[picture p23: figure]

Figure 5: CAD of the raised holding bay and new gate to push the weights up the incline.

## 2.4 Target Detection

Target detection had significant changes between the DDR and race day. In early testing, the ultrasounds worked fine for target detection. However, this testing generally was done at a computer with the robot sitting on a desk. It is easy to simulate good results with sensors when testing is performed in a controlled environment such as this. Further testing was completed in full arenas with obstacles, and it was found, target detection was very temperamental. Therefore, a new design with time-of-flight sensors was proposed, shown in Figure 4. This new design featured an additional time-of-flight on the top of the robot and switched out the two ultrasound sensors closer to the ground for time-of-flight sensors. The angle of these sensors was analysed to find the optimal angle for the highest success rate (Figure 6). Rather than pointing the sensors outwards to detect weights to the side of the robot, they pointed directly forwards with the outer edges of the FOV to be parallel with the side of the robot. This limited the width of the detection area but allowed the robot to stay locked on to a weight for longer and direct the weight accurately into the centre of the funnel. Through testing this showed a much higher chance of collection versus having the TOF sensors angled outwards. The new angle of the sensors relied on enough movement from navigating the arena to scan for weights potentially out to the side of the robot. The short range TOF sensors gained significant accuracy and speed over the ultrasound sensors which improved the robot’s function and reliability.

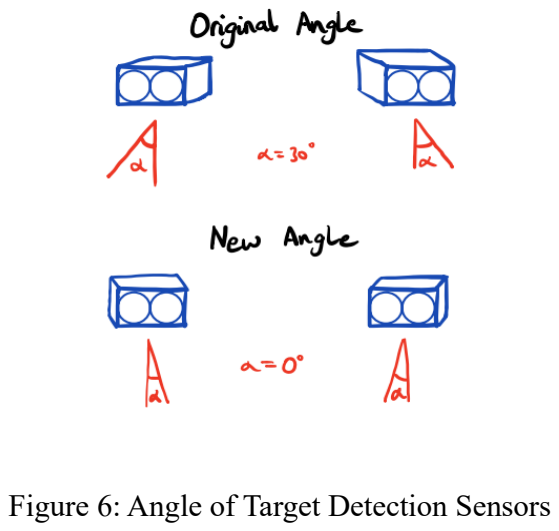
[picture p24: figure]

The new design also improved the ability to identify ramps. Previously, the ultrasounds would detect a ramp and identify it as a weight. It would then move into the weight collection state and get stuck on the ramp until the watchdog timer saved it. The new design checks if both bottom TOF see an object within 50mm and labels this as a ramp. This works since the sensors are now positioned parallel to each other, meaning they both would not detect a weight within this short distance.

## 2.5 Navigation

The Navigation for searching the playing field consisted of four TOF sensors on the top of the robot and two on the bottom. Two facing centre and two facing outwards on top as shown in Figure 7. The last two were used for the target collection sensors.


Figure 7: TOF sensor arrangement and front of robot.

This differed from the DDR report where the robot only used three on top and did not take advantage of the bottom two. The logic remains the same for majority of the functionality. Where the robot would travel forwards until it saw a wall then decide to turn the way which it saw the farthest out wall

Figure 6: Angle of Target Detection Sensors and keep turning until it no longer saw a wall right in front of it. Implementing the second centre top TOF consisted of returning the min between the two centre TOFs therefor kept the searching code the same. During testing of DDR, it was found that the robot could get stuck on the edges of walls. By implementing another TOF on top and pushing them further out increases the robot’s ability to see wall edges.

The Navigation of the ramp was to not go on it. From Target Detection 2.4 the robot would avoid the ramp often. If the robot found itself on the ramp by checking the IMU angle it would back but and avoid it. This removed the ramp from play for the robot.

To navigate home the robot remembers its x, y position using the motor encoders and IMU and uses this to calculate the angle home. It then heads in that direction until it finds an obstacle. It then follows around the obstacle until it can turn back to the heading home. The navigation home differs from the DDR in it now waits longer before turning back to home after encountering an obstacle this was done to stop it turning into poles.

# 3. Results

## 3.1 Competition Performance Review

Group 4 key strategy was to move out of base and collect all three target weights before 80 seconds and before the other teams whilst avoiding dummies. Then returning all weights home doubling our points. Figure 8, is an diagram of the algorithm.


Figure 8: Competition strategy

The robot placed 3

rd overall in the competition, which was due to the success of some systems, but the rounds lost were also due to the failure of other systems. The detection and collection systems worked well as the robot picked up at least one weight in all six competition rounds and satisfied requirement 1.10, 1.8 and 2.2. This was expected due to its very high success rate of picking up weights all throughout testing. The robot also successfully detected and ignored a dummy weight during one of the rounds which satisfied requirement 1.11. Other successful systems and requirements were the electronics and battery, the electronics never had issues such as cutting out and a battery could last nearly a full day of testing which fulfilled the performance requirement 2.1. The robot ran successfully when placed in multiple orientations in home base during testing and the last two rounds of competition.

There were many systems however that contributed to the loss of points for the first four rounds and to the loss of the last two rounds. The first two rounds the robot successfully picked up weights and then would get stuck in the arena. The first round, it was physically stuck on one of the poles from the track cap screw and the second round it was a software issue where it was locked on to the pole. Both prevented the robot from driving home but it won the round regardless. Both issues violated performance requirement 2.3 (do not get stuck) but were fixed after the second round. The case where the robot sensors got locked onto the pole is outlined in the FTA under software error, optimisation issue and then edge case error. A simple edge case was then implemented in code which solved this issue. The other case where the robot rotated around the pole is also outlined under the FTA where it was a mechanical error because the robot can’t move because something was in the way. An issue that came across during testing was the robot getting stuck on the corner of the ramp, a simple software change allowed the bottom TOF’s to detect it and navigate away from the ramp. To reduce the ability of the ramp causing more issues, an angle watchdog was implemented so if the robot’s angle of attack was greater than 6 degrees at any point in time it would turn around. This proved effective as it never occurred during rounds.

The system that ultimately caused us to lose the last round was the weight disposal. Throughout testing the weight disposal had been reliable if the tracks did not slip somewhere in the arena. The weights would be disposed in the back corner of the base as expected and there were only minor adjustments made. However, during three of the rounds on the last day of the competition, a total of 4 weights collected were dropped off mere inches outside of home base because the robot thought it was home. This was not caused by tracks slipping as during these three rounds. The encoders had minimal error in the rounds where weights were dropped poorly as most the edge cases where the tracks would slip had already been dealt with. The failure of the disposal system caused a major loss in points and violated the requirements 1.3 and 1.14. This fault was not outlined in the FTA as it did not come under the category “robot fails to collect weight”. The system failure was due to the poor strategy to drop the weights off at base but the reason for this strategy was ultimately the poor design of the weight storage. Since the weights had been lifted off the ground there was no designated method for dropping the weights off. If a method had been designed in tandem with the holding bay rather than after the fact, then the robot may have been able to deliver weights to inside the base.

A case that did not occur once during testing but happened twice during rounds was weights tipping over. The requirements originally specified that the robot shall be able to collect weights in any orientation, but when the design of the collection system was changed after the conceptual design report, this requirement became more overlooked as it never occurred. For the current design, the weight is required to be standing so that the rails of the holding bay can hook onto the weight and hold it. In round 5, a weight was knocked over in front of the robot and the robot continued to drive over top of it and its movement became impaired for the remainder of the round. This was unlucky and likely caused the round to be lost. This may have been able to be mitigated by allowing tipped over weights to slide under the centre to prevent getting stuck on top of it. A different occurrence happened in round 6 where one weight had been collected and the robot drove over the oppositions base rails and the weight caught on the rail and caused it to pop back out past the centre gate. This had also never occurred before but caused the weight to be dropped into the oppositions base and resulted in a loss.

## 3.2 Competitor 1 Review – Round 13

Round 13 was the first round for Group 4. Group 4 won the round with 2.25 points compared to 0 points from group 29’s robot. Group 4 robot collected 3 weights at time 9, 21 and 31 seconds. Compared to group 29 who collected no weights. Neither team had weights at home. Group 29 and 4 both collected all weights they saw hence lost none. Neither team collected any dummy weights. Group 4 travelled 5700 mm more than group 29. Neither team returned home nor dropped weights home. Both teams became stuck during the round group 29 at 13 seconds and Group 4 at 46 seconds. Table 1 summarises all performance metrics of the round.

Table 1: Performance metrics of round 13.

PERFORMANCE METRIC | GROUP 4 ROBOT | OPPONENTS ROBOT
| | GROUP 29
OFF HOME BASE | Yes | NO
WEIGHTS COLLECTED | 3 | 0
WEIGHTS AT HOME | 0 | 0
WEIGHTS SEEN | 3 | 0
DUMMY WEIGHTS | 0 | 0
WEIGHTS LOST | 0 | 0
TIME BEFORE GETTING STUCK | 46 s | 13 s
DISTANCE TRAVELLED ESTIMATE | 6000 mm | 300 mm
RETURNED HOME | NO | NO

Ultimately won what Group 4 the round was collecting more weights than group 29, but this is a consequence of time before getting stuck and distance travelled. Group 4 spent 33 more seconds searching and collecting weights before being stuck whilst group 29 was stuck.

This comes from how to two robots navigate. Group 4 had better navigation than group 29. Group 4 kept a further distance from the walls avoiding edges of walls. Figure 9 shows group 29 hitting the edge of the wall.


Figure 9: Group 29 Robot stuck on wall

It should be noted that on green base, group 29’s base, there was a broken part of the base barrier. This led robots to turn towards the broken part if one track went through the bump and the other track went over. This happened in the case of group 29 although the navigation system should’ve been able to deal with this edge case.

Group 4 navigation of moving into most free space and collection system allowed for the fastest collection of three weights in the round and competition. This proved to be advantageous in this round as there were only seven weights total. Another factor for fastest collection of three weights was Group 4’s robot could be started before the count down and would only move after the blue power button was pressed. This gave it a five second advantage over group 29

A failure of Group 4 was the robot getting stuck on a pole while returning home. Figure 10 shows an annotated figure of the robot oscillating before the pole and then getting the belt stuck on the pole.


Figure 10: Annotated Robot Stuck on Pole

When returning home to robot drives in the direction home until an obstacle then drives around the obstacle. The pole being narrow caused the robot to not see it think it had gone pass it then turn back into it. See it and repeat trying to go around it. Eventually got close enough to get caught on it and spin indefinitely around it. The FTA discussed the potential of unexpected looping behaviours from code. A watchdog was included but as the robot thought it was moving home and it could not see the pole so it wasn’t triggered.

It is hard to evaluate group 29 performance as they did not make it out of home. This is likely due to no TOFs facing outwards hence not being able to see to the side of the robot. It uses a machine learning method for searching. Wheels were the given setup. The way it collected weight was a strong point for it and held an advantage over Group 4. It used a combination of a metal laced ramp and a scope to grab weights and check if metal by passing a current through the weights. This has the potential to pick up multiple weights at a time unlike Group 4. In later rounds of the competition this feature proved important often winning rounds.

## 3.3 Competitor 2 Review – Round 63

In round 63 Group 4 competed against Group 1. Group 1’s robot shown in Figure 11, featured a combine system with rotating rubber bands. It also featured a shorter wheelbase and a larger overall height. This system is beneficial for an instance where there are multiple weights close together as the combine can collect a lot of weights without necessarily sensing all of them. This would require a good dummy weight rejection system however this was not needed in this round as they didn’t pick any dummy weights up.


Group 1 won this round with 3.75 points while Group 4 achieved 0.75 points. Group 1 managed to get two weights to their home base contributing to all their large number of points. Group 4 had one weight on board the robot. At the start, both robots were facing towards each other with a weight in between. Group 4 was first off home base and collected the first weight. Group 1 collected their first weight at 60 s. A summary of performance metrics for round 63 is displayed in Table 2.

Table 2: Performance metrics of round 63.

PERFORMANCE METRIC | GROUP 4 ROBOT | OPPONENTS ROBOT
| | GROUP 1
OFF HOME BASE | Yes | Yes
WEIGHTS COLLECTED | 1 | 0
WEIGHTS AT HOME | 0 | 2
WEIGHTS SEEN | 2 | 2
DUMMY WEIGHTS | 0 | 0
WEIGHTS LOST | 1 | 0
TIME BEFORE GETTING STUCK | 27 s | 67 s
DISTANCE TRAVELLED ESTIMATE | 3000 mm | 4000 mm
RETURNED HOME | YES | YES
TIME TO FIRST WEIGHT | 4 s | 60 s

Group 4 tipped over the second weight as it was being collected, shown in Figure 12. Group 1 did not face this problem due to their combine system having the ability to collect tipped over weights. This is one of the main reasons Group 1 won this round as Group 4 was stuck in this way for most of the round. Group 1’s robot was slightly faster than Group 4’s robot despite being a larger robot and weighing more. This improved speed is due to a larger drive wheel allowing the robot to move faster. Group 1 also featured a good weight drop system with both their weights being dropped home successfully. The robot completed a 180 degree turn once reaching their base before tipping the weights into home in a smooth manner. Overall group 1 won this round due to their combine collection system and effective home drop system.

Figure 11: Group 1 Robot
(1st overall)


## 3.4 Competitor 3 Review – Round 65


In round 65, Group 4 competed against group 13. Group 13 won the round with a score of 3.75
against Group 4 with a score of 0.75. Group 4 collected 3 weights over the round but unfortunately one weight fell out into group 13’s base and another weight was dropped outside of home base. Group 13 collected 4 weights onboard, 3 target and one dummy. It took 20 seconds for group 13 to collect 3 targets and one dummy whereas it took 60 seconds for Group 4 to collect 3 target weights. The results of round 65 are summarised in Table 3.

Group 13’s robot is shown in Figure 13. The drivetrain and chassis of group 13 was similar to Group 4 with one minor difference. Both robots
used the standard chassis plates, extrusions, DC
motors, 3D printed drive pulley and tracks, but
group 13 used larger 3D printed bearing casings for the tracks to roll on. This gave the robot a height advantage to clear more obstacles and have less chance of getting stuck. Though neither robot got stuck in this round, the height difference could have been advantageous to Group 4 where the weight got caught on group 13’s base and dropped the weight into their base.

Group 13’s robot used a total of seven range finding sensors, two ultrasonic and five TOF sensors. The ultrasonic sensors and two long range TOF sensors were used for navigation and obstacle avoidance. The ultrasonic sensors were pointed directly outwards sideways and the TOF’s were pointed forwards and out at an angle of 45 degrees. This configuration was evident as to why they often collided with obstacles head on and spent a portion of time sitting at an obstacle waiting for a watchdog timer. The sensor configuration of Group 4 was slightly better as the robot had better

Figure 13: Group 13 robot (2nd overall)

Figure 12: Round 63 Tipped Weight obstacle avoidance though this had little influence on the performance of both robots. The remaining three TOF sensors were the short-range version and were lined up along the bottom of the robot to detect weights. This gave the robot a large FOV for finding weights but due to the lack of forward-facing sensors above the lower TOF’s, Group 4’s strategy of comparing bottom sensors to top sensors to identify weights is not practical. Instead, the robot drives towards anything the lower sensors see. However, this method of detection did not limit the robot as it scored well.

It was evident that the motion control of group 13’s robot used some form of PID control or smoothed motion as its movement around the arena was smooth with corners and straights, compared to Group 4 where motion was ‘bang-bang’. This allowed group 13’s robot to navigate through and beside obstacles smoother than Group 4’s but still hit obstacles head on. It was also evident that group 13 could not return home as after their robot had collected 4 weights it stopped in an open area. Group 4’s robot made it to home base but slightly misjudged and still dropped one weight outside of base therefore the advantages of making it home actually caused loss of points.

For collecting weights, group 13’s robot utilised a U-shaped arm with an electro-magnet in the centre. The arm was controlled by two HX12 servos and could only pick up weights standing up with metal tops sitting directly in front of the centre TOF sensor. The weights would then be lifted on board and placed on a tray, but weights would not be checks weather they are a target or a dummy. This resulted in group 13 collecting a dummy weight so theoretically, Group 4’s weight collection outperformed group 13’s by collecting the same number of target weights. The advantage of Group 4’s collection system was that penalties were applied for collected dummy weights but Group 4’s deposit system and storage let it down by losing weights collected.

Table 3: Performance metrics of round 65.

PERFORMANCE METRIC | GROUP 4 ROBOT | OPPONENTS ROBOT
| | GROUP 13
OFF HOME BASE | Yes | Yes
WEIGHTS COLLECTED | 3 | 4
WEIGHTS AT HOME | 0 | 1
WEIGHTS SEEN | 4 | 5
DUMMY WEIGHTS | 0 | 1
WEIGHTS LOST | 2 | 0
TIME BEFORE GETTING STUCK | N/A | 85 s
DISTANCE TRAVELLED ESTIMATE | 12000 mm | 9000 mm
RETURNED HOME | YES | NO
TIME TO FIRST WEIGHT | 4 s | 6 s

## 3.5 Post-mortem summary

From 3.1, the major flaw in the robot was the package delivery system for off-loading weights from the robot to home. Introducing a system where the robot does not have to move more than one turn once on home base would increase reliability and avoid dropping weights out of home. A screw that pushed the weights out the back could have been effective. Where the robot would just have to get home and turn around. This would have also been faster than the current method. Another method could be another the weights stored sloped down such that when the gates open, they slide out. This system working reliably would have helped the robot win more rounds. If the robot had deposited weights correctly in the competition, it would have achieved getting four weights in base across all rounds.

Another flaw was becoming stuck on fallen weights making the encoder and therefore the x, y position of the robot useless. Implementing a system such that it would not be stuck longer than 5 seconds would mitigate this. This could be integrating the IMU accelerometer data into the x, y positioning system. By doing so there would be two sensors taking odometry data and went they become unaligned, the robot is most likely stuck and should attempt to reverse. Another solution could be to allow fallen weights to slide under the robot by lifting the entire tray up. Therefore, it would not get stuck on them at all.

# 4. Conclusion

After completing the Robocup competition, the robot can be defined as ‘fit for purpose’ as it meets most of the requirement’s specifications. However, the robot did not consistently pass functional requirements 1.3 and 1.9, while it did not pass performance requirement 2.3 during some rounds. All operational requirements, non-functional requirements and constraints were passed, see appendix B. Overall, the robot was successful as it placed 3rd in the competition winning four rounds. Requirements on pole obstacles would have improved performance.

The areas for improvement include fixing these functional and performance requirements which mostly occurred due to the robot getting stuck on poles and inability to pick up tipped over weights. The weight deposit system takes a lot of time and often pushes the weights off the home base. Further development time could have been spent on improving this system. It could be improved by a sloped ramp so that the weights fall out of the robot due to gravity. The current system has a lengthy move forward and backwards to shunt the weights out. There could also be a check for tipped over weights within code to move backwards and away if it is in the weight collection state for a certain amount of time.

We used 386 grams of PLA for 3D printing, but 300 grams of PLA was included in the budget. This resulted in an extra cost in PLA of $4.30 NZD. All parts designed were manufactured using 3D print except the main gate, this will be milled out of aluminium for strength as it provides a stronger mounting point to the servo. The aluminium has an approximate extra cost of $3.90 NZD. We used two extra TOF sensor (long-range) than what was provided, this had an extra cost of $20 NZD. Everything else is included in the budget. The total additional cost of the robot came out to $28.20 NZD which is well within the additional costs budget of $50. A full bill of materials can be found in appendix A.

# Appendix

## A. Bill of Materials

Part Description | Part Number | Cost per Unit ($ NZD) | Quantity | Additional Costs
Teensy 4.0 MCU | TEENSY40 | 23.80 | 1
Chassis Plates | | | 2
Robot tracks | 880-8M | | 2
Drive Pulley | | | 2
Track Bearings | | | 10
Electrical Plate | | | 1
Aluminium Ex. 223.5mm | | | 6
Digital Level Shift | | | 1
Inductive Level Shift | | | 1
Encoder Board | | | 1
DC Motor Driver | | | 2 1
Power Supply Module | | | 1
Power Buttons | | | 1
Colour Sensor | TCS34725 | 14.00 | 1
Ultrasound Board | | 1.00 | 1
Ultrasound Sensors | HC-SR04 | 1.80 | 2
TOF sensor (Long) | VL53L1XV2 | 10.00 | 2+2 | $20.00
TOF sensor (Short) | VL53L0XV2 | 5.00 | 2
IMU Sensor | SEN0253 | 36.00 | 1
Inductive Proximity | LJ18A | 25.00 | 1
Digital IR Sensor | SEN0019 | 6.00 | 1
Servo | HX12K | 14.00 | 1
Servo | SG90 | 2.50 | 1
DC Motor with encoder | 28PA51G | 70.00 | 2
DC Motor 200RPM | SKU505979 | 15.00 | 2
Aluminium Billet | | $11.40 per 100x100x15mm | 75x45x15mm | $3.90
PLA | | 0.05 per g | 386 g | $4.30
| | | Total: | $28.20

## B. Requirement Specifications

Functional | Description | Pass/fail
1.1 | The Robot shall be able to recognise if it is at ‘home’ or in the playing arena | PASS
1.2 | The Robot shall be able to distinguish between its home and its opponent’s home. | PASS
1.3 | If the Robot is positioned at its home and contains weights, it must place the weights on home. | FAIL
1.4 | The Robot should return home once it contains three weights. | PASS
1.5 | The Robot shall be able to recognise walls in relation to itself. | PASS
1.6 | The Robot shall be able to traverse all the following obstacles: | PASS
1.6.1 | Speedbumps of minimum 25mm high. | PASS
1.6.2 | Ramps of minimum 100mm high and 30% gradient. | PASS
1.7 | The Robot shall be no greater than 400 mm wide. | PASS
1.8 | If the Robot detects a weight in the arena, it shall be able to move towards it successfully. | PASS
1.9 | The Robot shall be able to collect weights placed in any orientation. | FAIL
1.10 | The Robot shall only collect weights in the playing arena. | PASS
1.11 | The robot should not collect fake weights. | PASS
1.12 | The robot shall be able to collect weights against arena walls and obstacles. | PASS
1.13 | Once identified The Robot should not interact with a dummy weight consecutively. | PASS
1.14 | The Robot shall cash in weights before the end of the round. | PASS

### Performance

2.1 | The Robots battery shall last for at minimum, 2 minutes. | PASS
2.2 | The Robot shall be able to pick up a weight once it enters a picking up mode within 5 seconds. | PASS
2.3 | The Robot shall not be stuck on in a subsection of the arena for more than 20 seconds | FAIL
2.4 | The Robot shall be able to move at least 0.5 m/s whilst fully loaded. | PASS

### Operational

3.1 | The Robot shall be robust enough to be hit by other robots. | PASS
3.2 | The Robot shall operate in temps ranges of 5 – 40 °C. | PASS
3.3 | The Robot shall function no matter the starting orientation and position. | PASS

Non-functional
4.1 | The Robot should have a mechanical modular design for easy assembly and repair. | PASS
4.2 | The Robot should withstand collisions with other robots and obstacles. | PASS

### Constraints

5.1 | The robot must not contain any more than 400 grams of 3D printed material. | PASS
5.2 | The robot must not use any externally sourced parts (outside of university). | PASS

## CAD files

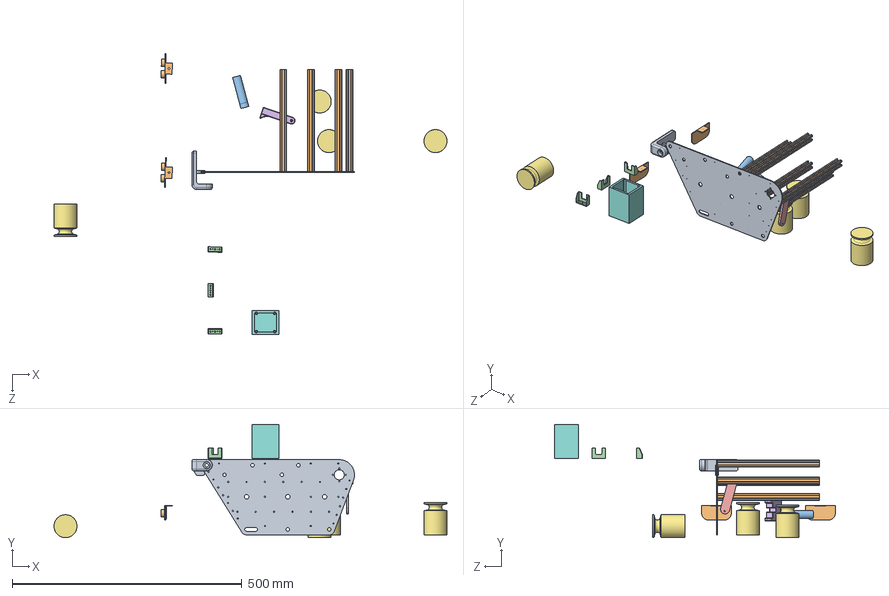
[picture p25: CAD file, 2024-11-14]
CAD/Assembly.SLDASM
856.0 x 247.0 x 611.8 mm
1515 Aluminum Extrusion x 5
Chassis
BatteryHolderV1
Weight x 4
Gate
Rear Gate
TOFsMount x 3
InductiveProxSensor
UltrasonicSensor x 2
Top_Bumpers

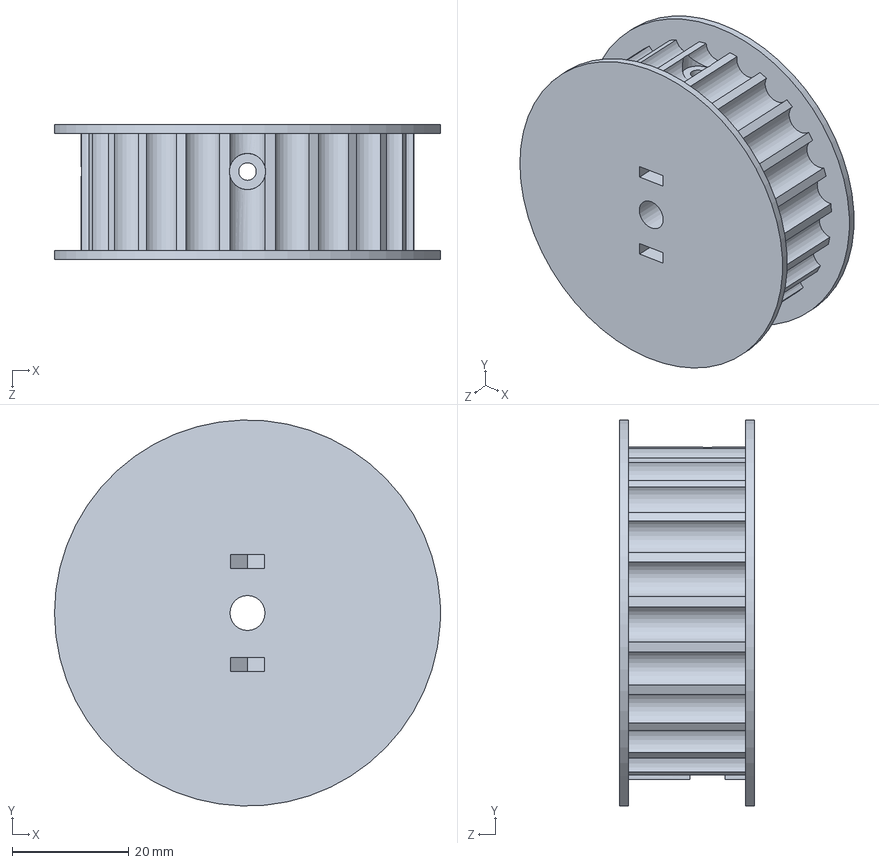
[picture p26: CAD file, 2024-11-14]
CAD/MainBeltDrive.SLDPRT
66.0 x 66.0 x 23.0 mm

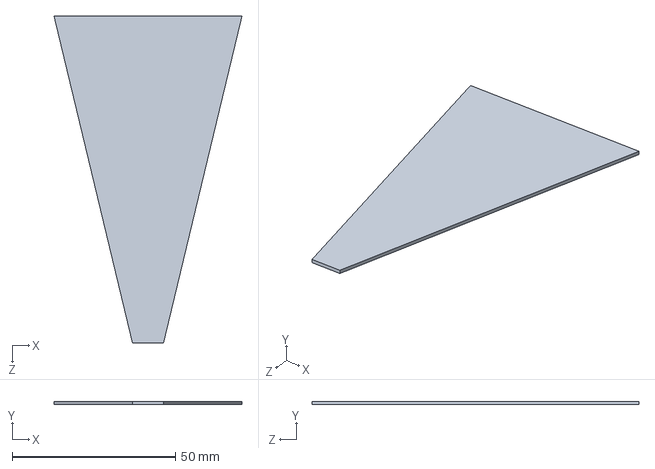
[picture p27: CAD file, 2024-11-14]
CAD/LongTOFAngle.SLDPRT
57.5 x 1.00 x 100.0 mm

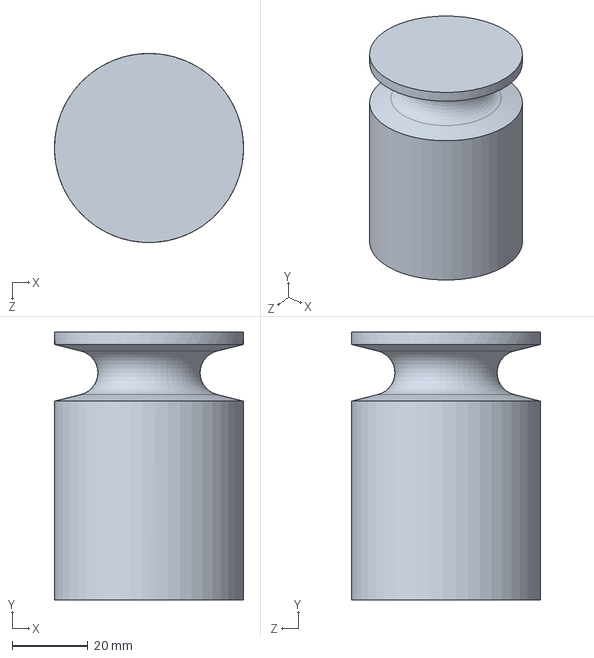
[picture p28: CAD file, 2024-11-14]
CAD/Weight.SLDPRT
50.1 x 71.0 x 50.1 mm

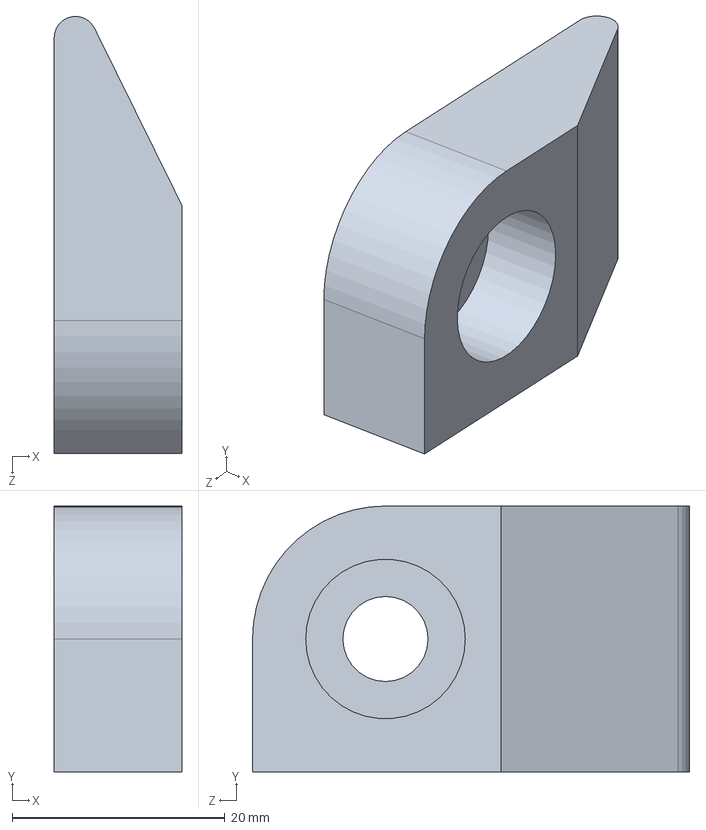
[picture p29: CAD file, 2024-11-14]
CAD/Bot_Bumpers.SLDPRT
12.0 x 25.0 x 41.1 mm

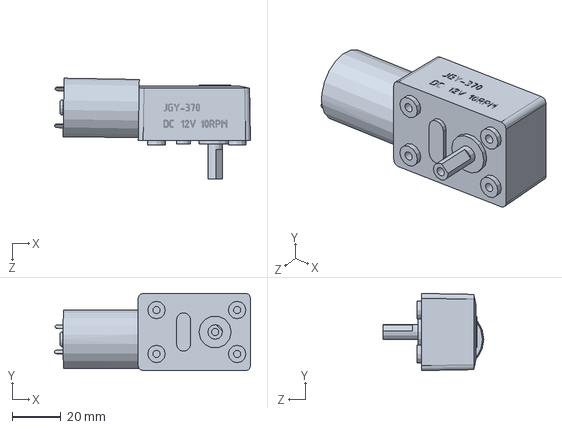
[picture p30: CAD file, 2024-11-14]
CAD/DCMotorWheel.SLDPRT
80.3 x 31.6 x 41.2 mm

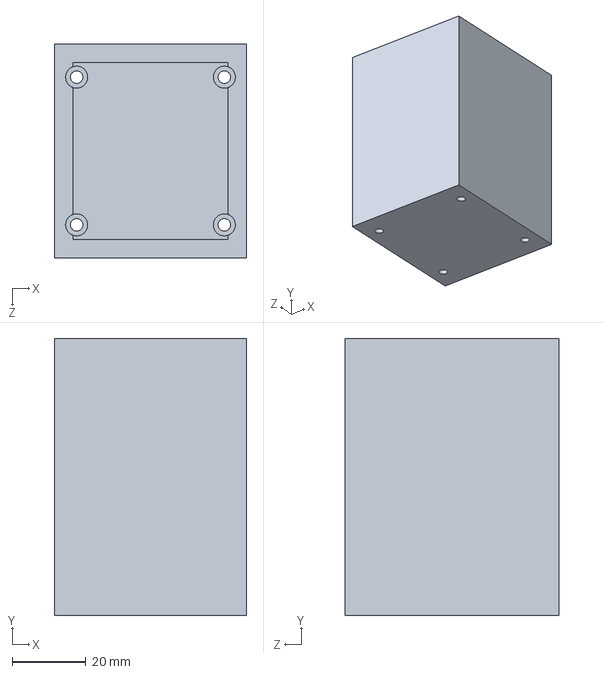
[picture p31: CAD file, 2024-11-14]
CAD/BatteryHolderV1.SLDPRT
52.0 x 75.0 x 58.0 mm

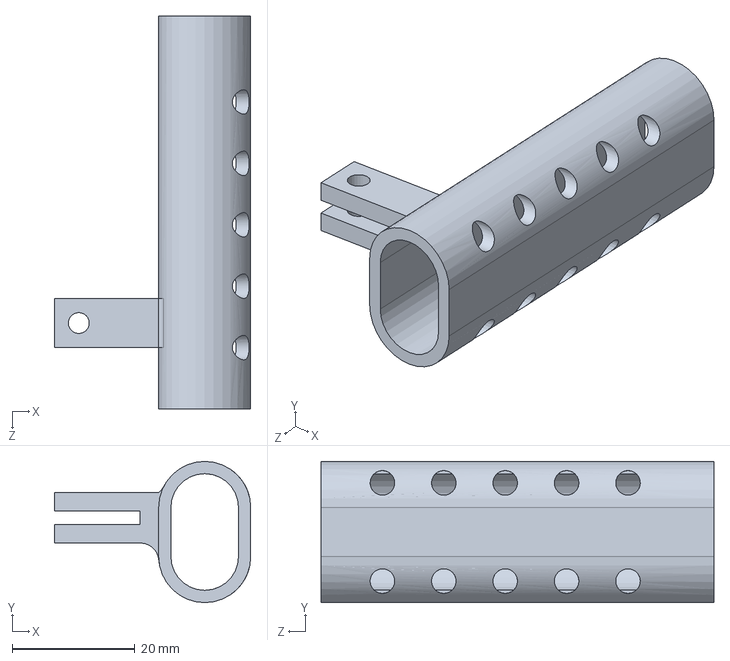
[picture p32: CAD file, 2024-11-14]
CAD/WireChannelHort.SLDPRT
32.0 x 23.0 x 64.0 mm

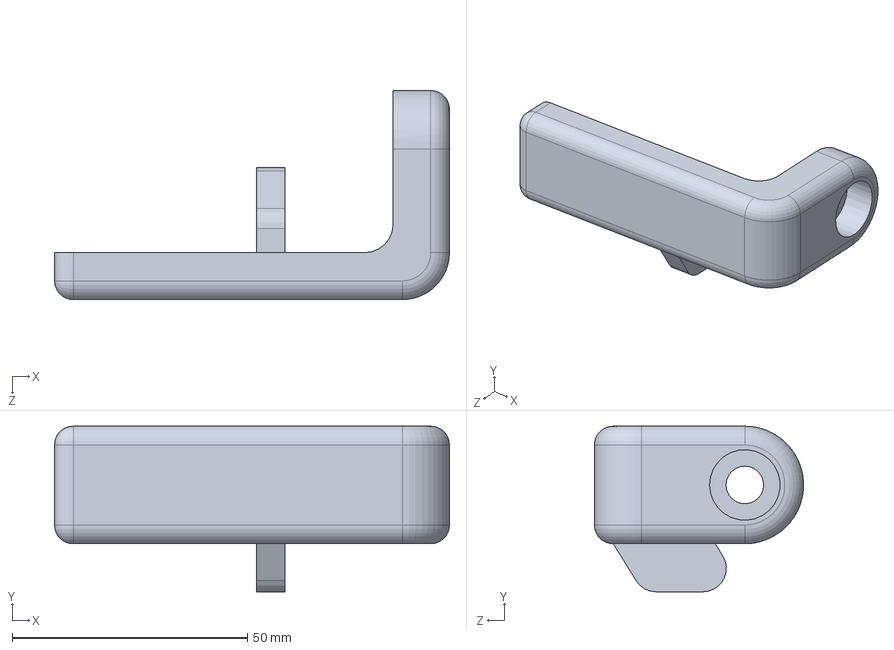
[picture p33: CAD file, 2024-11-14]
CAD/Top_Bumpers.SLDPRT
84.0 x 35.2 x 44.5 mm

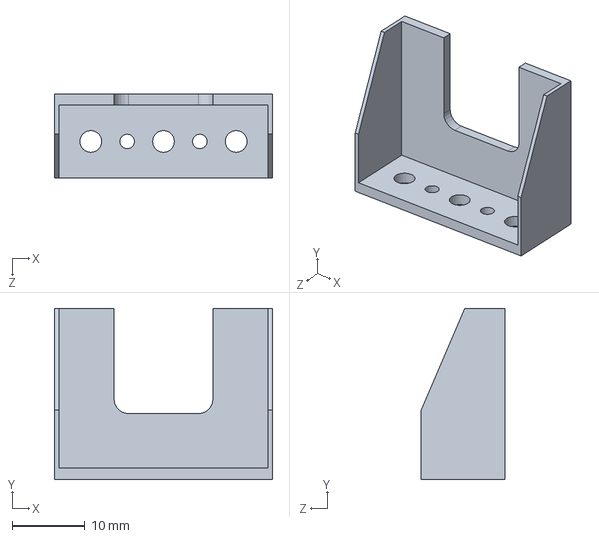
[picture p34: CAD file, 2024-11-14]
CAD/TOFsMount.SLDPRT
30.0 x 23.6 x 11.5 mm

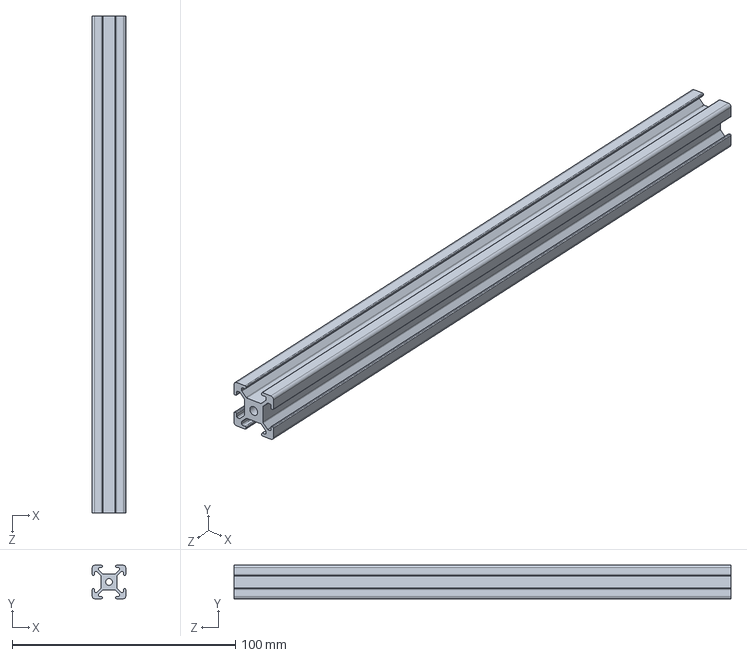
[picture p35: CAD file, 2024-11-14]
CAD/1515 Aluminum Extrusion.SLDPRT
15.0 x 15.0 x 222.5 mm

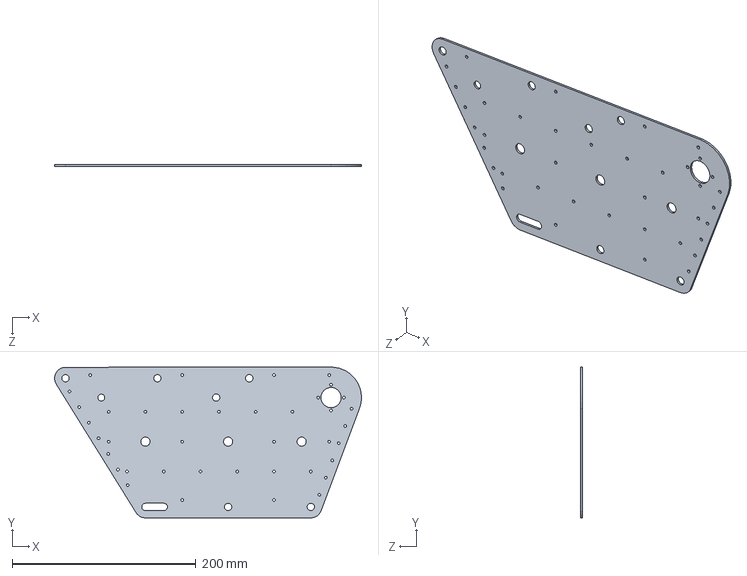
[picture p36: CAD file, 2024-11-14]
CAD/Chassis.SLDPRT
334.1 x 164.2 x 2.00 mm

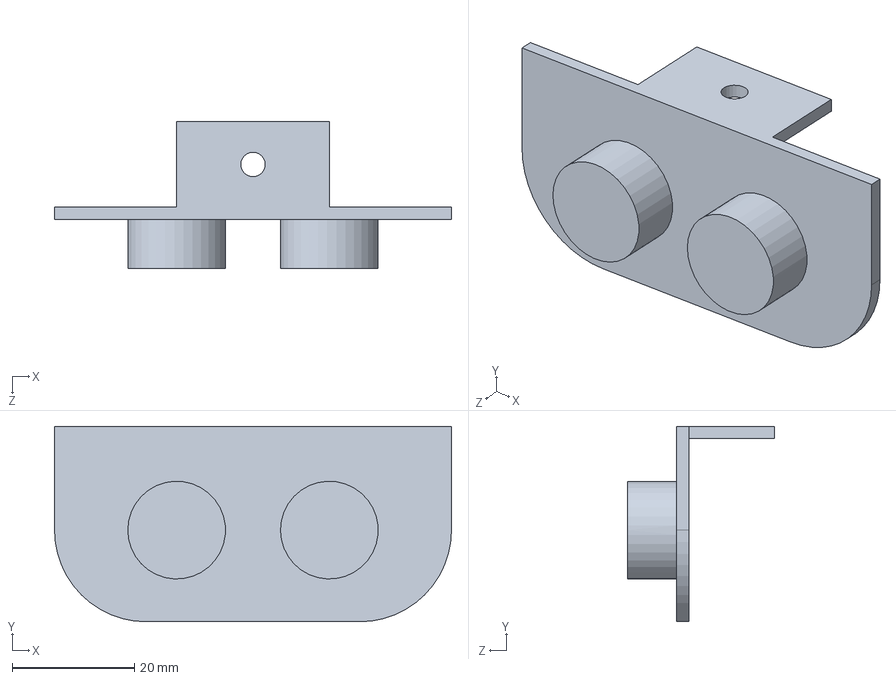
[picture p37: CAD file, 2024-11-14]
CAD/UltrasonicSensor.SLDPRT
65.0 x 32.0 x 24.0 mm

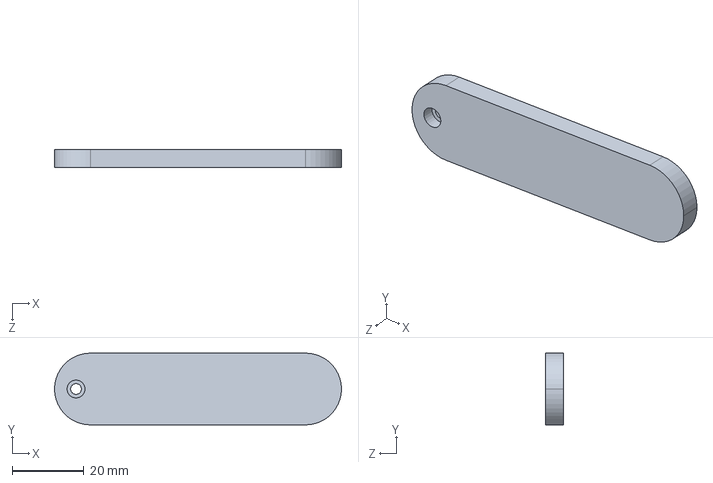
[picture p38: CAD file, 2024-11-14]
CAD/Rear Gate.SLDPRT
80.0 x 20.0 x 5.00 mm

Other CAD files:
CAD/Weight Sensor Diagram.SLDPRT
CAD/Bot_Bumpers_left.SLDPRT
CAD/InductiveProxSensor.SLDPRT
CAD/Gate.SLDPRT
CAD/ColourSensor.SLDPRT
CAD/Digital_IR_Sensor.SLDPRT
CAD/LH TRAY NEW SLOT.SLDPRT
CAD/LH TRAY.SLDPRT
CAD/Partition.SLDPRT
CAD/RH TRAY.SLDPRT
CAD/RH Tray Back.SLDPRT
CAD/RH Tray Front.SLDPRT
CAD/Top_Bumpers right.SLDPRT
CAD/WireChannelVert.SLDPRT
CAD/digitalBoardBracket.SLDPRT
CAD/digitalBoardBracket2.SLDPRT
CAD/inductiveBoardBracket.SLDPRT

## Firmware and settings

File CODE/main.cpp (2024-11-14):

/********************************************************************************
 *                                   ROBOCUP                              
 *        
 *  main.cpp only runs the task schedular
 *  Refer to finite_state_machine for functionality   
 *  
 *  Template by: Logan Chatfield, Ben Fortune, Lachlan McKenzie, Jake Campbell
 * 
 *  Written By:
 *            Mark   Day
 *            Jack   Wilson
 *            Kieran James
 ******************************************************************************/

#include <Wire.h>                   
#include <TaskScheduler.h>          

// Custom headers
#include "motors.h"
#include "sensors.h"
#include "weight_collection.h"
#include "return_to_base.h" 
#include "finite_state_machine.h"
#include "smartmove.h"

//**********************************************************************************
// Local Definitions
//**********************************************************************************

// Task period Definitions
#define IR_READ_TASK_PERIOD                 100
#define INDUCTIVE_READ_TASK_PERIOD          100
#define COLOUR_READ_TASK_PERIOD             500
#define SET_MOTOR_TASK_PERIOD               50
#define WEIGHT_SCAN_TASK_PERIOD             50

#define PRINT_TOF_SERIAL_TASK_PERIOD        100
#define RUN_FINITE_STATE_TASK_PERIOD        80
#define PRINT_ENCODER_SERIAL_TASK_PERIOD    40
#define IMU_TASK_PERIOD                     40 
#define POS_TASK_PERIOD                     100
#define HOME_VECTOR_TASK_PERIOD             100
#define ODOMETRY_TASK_PERIOD                40
#define PRINT_WEIGHT_SCAN_TASK_PERIOD       50
#define UPDATE_TOF_TASK_PERIOD              50


// Task execution amount definitions
#define IR_READ_TASK_NUM_EXECUTE           -1
#define INDUCTIVE_READ_TASK_NUM_EXECUTE    -1
#define COLOUR_READ_TASK_NUM_EXECUTE       -1
#define SET_MOTOR_TASK_NUM_EXECUTE         -1
#define WEIGHT_SCAN_TASK_NUM_EXECUTE       -1

#define PRINT_TOF_SERIAL_NUM_EXECUTE       -1
#define RUN_FINITE_STATE_NUM_EXECUTE       -1
#define PRINT_ENCODER_SERIAL_NUM_EXECUTE   -1
#define IMU_NUM_EXECUTE                    -1
#define POS_NUM_EXECUTE                    -1
#define HOME_VECTOR_NUM_EXECUTE            -1
#define ODOMETRY_NUM_EXECUTE               -1
#define PRINT_WEIGHT_SCAN_NUM_EXECUTE      -1
#define UPDATE_TOF_NUM_EXECUTE             -1


// Pin deffinitions
#define IO_POWER  49


// Serial deffinitions
#define BAUD_RATE 115200 


//**********************************************************************************
// Function Definitions
//**********************************************************************************
void pin_init();
void robot_init();
void task_init();


//**********************************************************************************
// Task Scheduler and Tasks
//**********************************************************************************

// Tasks for reading sensors 
Task tRead_infrared(      IR_READ_TASK_PERIOD,                IR_READ_TASK_NUM_EXECUTE,             &read_infrared);
Task tRead_inductive(     INDUCTIVE_READ_TASK_PERIOD,         INDUCTIVE_READ_TASK_NUM_EXECUTE,      &read_inductive);
Task tRead_colour(        COLOUR_READ_TASK_PERIOD,            COLOUR_READ_TASK_NUM_EXECUTE,         &read_colour);
Task tPrintTofserial(     PRINT_TOF_SERIAL_TASK_PERIOD,       PRINT_TOF_SERIAL_NUM_EXECUTE,         &PrintTofSerial);
Task tPrintEncoderSerial( PRINT_ENCODER_SERIAL_TASK_PERIOD,   PRINT_ENCODER_SERIAL_NUM_EXECUTE,     &printEncoderSerial);
Task tImuRefresh(         IMU_TASK_PERIOD,                    IMU_NUM_EXECUTE,                      &IMUloop);
Task tUpdateTof(          UPDATE_TOF_TASK_PERIOD,             UPDATE_TOF_NUM_EXECUTE,               &updateTof);

// Task to set the motor speeds and direction
Task tSet_motor(          SET_MOTOR_TASK_PERIOD,              SET_MOTOR_TASK_NUM_EXECUTE,           &set_motor);
Task tOdomReading(        ODOMETRY_TASK_PERIOD,               ODOMETRY_NUM_EXECUTE,                 &OdomReading);
Task tCalcPos(            POS_TASK_PERIOD,                    POS_NUM_EXECUTE,                      &CalcPos);
Task tCalcHome(           HOME_VECTOR_TASK_PERIOD,            HOME_VECTOR_NUM_EXECUTE,              &CalcHome);

// Tasks to scan for weights and collection upon detection
Task tWeightScan(         PRINT_WEIGHT_SCAN_TASK_PERIOD,      PRINT_WEIGHT_SCAN_NUM_EXECUTE,        &weight_scan);

Task trunStateMachine(    RUN_FINITE_STATE_TASK_PERIOD,       RUN_FINITE_STATE_NUM_EXECUTE,         &runStateMachine);
Scheduler taskManager;


//**********************************************************************************
// put your setup code here, to run once:
//**********************************************************************************
void setup() {
  Serial.begin(BAUD_RATE);
  pin_init();
  Wire.begin();
  motor_init();
  TofSensorInit();
  encoderSetUp();
  IMUsetup();
  task_init();
  robot_init();
  colourSetup();
  init_infrared();
  setHomeColour();
}


//**********************************************************************************
// Initialise the pins as inputs and outputs (otherwise, they won't work) 
// Set as high or low
//**********************************************************************************
void pin_init(){
    
    Serial.println("Pins have been initialised \n"); 

    pinMode(IO_POWER, OUTPUT);              //Pin 49 is used to enable IO power
    digitalWrite(IO_POWER, 1);              //Enable IO power on main CPU board
    pinMode(START_BUTTON, INPUT);
}


//**********************************************************************************
// Set default robot state
//**********************************************************************************
void robot_init() {
    Serial.println("Robot is ready \n");
}


//**********************************************************************************
// Initialise the tasks for the scheduler
//**********************************************************************************
void task_init() {  
  taskManager.init();     
  taskManager.addTask(tRead_infrared);
  taskManager.addTask(tRead_inductive);
  taskManager.addTask(tRead_colour);
  taskManager.addTask(tSet_motor); 
  taskManager.addTask(tPrintTofserial);
  taskManager.addTask(trunStateMachine);
  taskManager.addTask(tPrintEncoderSerial);
  taskManager.addTask(tImuRefresh);
  taskManager.addTask(tOdomReading);
  taskManager.addTask(tCalcPos);
  taskManager.addTask(tCalcHome);
  taskManager.addTask(tWeightScan);
  taskManager.addTask(tUpdateTof);

  tRead_infrared.enable();
  tRead_inductive.enable();
  tRead_colour.enable();
  tSet_motor.enable();
  tPrintTofserial.enable();
  trunStateMachine.enable();
  tImuRefresh.enable();
  tOdomReading.enable();
  tCalcPos.enable();
  tCalcHome.enable();
  tWeightScan.enable();
  tUpdateTof.enable();


 Serial.println("Tasks have been initialised \n");
}



//**********************************************************************************
// MAIN LOOP
//**********************************************************************************
void loop() {
  taskManager.execute();
}

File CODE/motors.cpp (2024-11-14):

/************************************
 *            motors.cpp            *
 * 
 * Motor outputs functions
 * 
 * Arthors 
 *        Mark   Day
 *        Jack   Wilson
 *        Kieran James
 *************************************/


#include <Servo.h>
#include <stdint.h>
#include "Arduino.h"

#include "motors.h"
#include "sensors.h"


//**********************************************************************************
//motor speed globals
//**********************************************************************************
#define LEFT_MOTOR_ADDRESS              0      
#define RIGHT_MOTOR_ADDRESS             1     
#define MIN_SPEED_CAP                   1050           
#define MAX_SPEED_CAP                   1950
#define MOTOR_STOP_SPEED                1500
#define MOTOR_SPEED_MULITPLIER          450
#define MOTOR_DRIFT                     30
static uint16_t g_rightMotorSpeed =     MOTOR_STOP_SPEED; //above 1500 forwards
static uint16_t g_leftMotorSpeed =      MOTOR_STOP_SPEED; //below 1500 forwards


//**********************************************************************************
//globals for dc motor encoder
//**********************************************************************************
volatile int encoderPos1 =  0;
int lastReportedPos1 =      1;
volatile int encoderPos2 =  0;
int lastReportedPos2 =      1;
boolean A_set1 =            false;
boolean B_set1 =            false;
boolean A_set2 =            false;
boolean B_set2 =            false;

//globals for odometry in mm
#define ENCODER_TO_1000MM 85
static float g_odom = 0;
static float prevEncoder1;
static float prevEncoder2;
enum PinAssignments {
  encoder1PinA = 2,
  encoder1PinB = 3,
  encoder2PinA = 4,
  encoder2PinB = 5,
};


//**********************************************************************************
// Servo gate assignments
//**********************************************************************************
#define BACKGATE_PIN      7
#define FRONTGATE_PIN     8

#define FRONT_CENTRE      1700
#define FRONT_CLOSE       800
#define FRONT_OPEN        2500
#define FRONT_HALF_OPEN   2100
#define FRONT_HALF_CLOSE  1350

#define BACKOPEN          2250
#define BACKCLOSED        1750

typedef enum {
  CENTRE,
  LEFT,
  RIGHT,
  OPEN,
  CLOSED,
} GatePos;
GatePos g_FrontGatePOS = CENTRE;
GatePos g_BackGatePOS = CLOSED;

Servo leftMotor, rightMotor, frontGate, backGate;


//**********************************************************************************
// Motor Init
//**********************************************************************************
void motor_init(void) {
  leftMotor.attach(LEFT_MOTOR_ADDRESS);
  rightMotor.attach(RIGHT_MOTOR_ADDRESS);
  frontGate.attach(FRONTGATE_PIN);
  backGate.attach(BACKGATE_PIN);

  frontGateCentre();
  BackGateClose();
}

//**********************************************************************************
// Check Speed Limits
//**********************************************************************************
uint16_t check_speed_limits(uint16_t speed) {
  if (speed > MAX_SPEED_CAP ){
    speed = MAX_SPEED_CAP;
  } else if (speed < MIN_SPEED_CAP) {
    speed = MIN_SPEED_CAP;
  }
  return speed;
}


//**********************************************************************************
// Set Motor
//**********************************************************************************
void set_motor(void) {
  g_leftMotorSpeed = check_speed_limits(g_leftMotorSpeed);
  g_rightMotorSpeed = check_speed_limits(g_rightMotorSpeed);
  leftMotor.writeMicroseconds(g_leftMotorSpeed);
  rightMotor.writeMicroseconds(g_rightMotorSpeed);
}


//**********************************************************************************
// Basic Move Functions 
//**********************************************************************************
void MoveForward(uint8_t speed) 
{
  g_rightMotorSpeed = MOTOR_STOP_SPEED - ((MOTOR_SPEED_MULITPLIER * speed)/ 10);
  g_leftMotorSpeed = MOTOR_STOP_SPEED + ((MOTOR_SPEED_MULITPLIER * speed)/ 10) - MOTOR_DRIFT; 
}


void MoveBackward(uint8_t speed)
{
  g_rightMotorSpeed = MOTOR_STOP_SPEED + (MOTOR_SPEED_MULITPLIER * speed)/ 10;
  g_leftMotorSpeed = MOTOR_STOP_SPEED - (MOTOR_SPEED_MULITPLIER * speed)/ 10;
}


void TurnLeft(uint8_t speed)
{
  g_rightMotorSpeed = MOTOR_STOP_SPEED - (MOTOR_SPEED_MULITPLIER * speed)/ 10;
  g_leftMotorSpeed = MOTOR_STOP_SPEED - (MOTOR_SPEED_MULITPLIER * speed)/ 10;
}


void TurnRight(uint8_t speed)
{
  g_rightMotorSpeed = MOTOR_STOP_SPEED + (MOTOR_SPEED_MULITPLIER * speed)/ 10;
  g_leftMotorSpeed = MOTOR_STOP_SPEED + (MOTOR_SPEED_MULITPLIER * speed)/ 10;
}

//**********************************************************************************
// Move for time
//**********************************************************************************
void TurnLeftForTime(uint8_t speed, unsigned long duration)
{
  TurnLeft(speed);
  set_motor();
  delay(duration);
  g_rightMotorSpeed = MOTOR_STOP_SPEED;  
  g_leftMotorSpeed = MOTOR_STOP_SPEED;  
}


void TurnRightForTime(uint8_t speed, unsigned long duration)
{
  TurnRight(speed);
  set_motor();
  delay(duration);
  g_rightMotorSpeed = MOTOR_STOP_SPEED;  
  g_leftMotorSpeed = MOTOR_STOP_SPEED;  
}


//**********************************************************************************
// Encoder
//**********************************************************************************
void encoderSetUp(void)
{
  pinMode(encoder1PinA, INPUT);       
  pinMode(encoder1PinB, INPUT); 
  pinMode(encoder2PinA, INPUT); 
  pinMode(encoder2PinB, INPUT); 
  attachInterrupt(digitalPinToInterrupt(2), doEncoder1A, CHANGE);  
  attachInterrupt(digitalPinToInterrupt(4), doEncoder2A, CHANGE);
}


void printEncoderSerial(void)
{
  if ((lastReportedPos1 != encoderPos1)||(lastReportedPos2 != encoderPos2)) 
  {
    Serial.print("Index:");
    Serial.print(encoderPos1, DEC);
    Serial.print(":");
    Serial.print(encoderPos2, DEC);
    Serial.println();
    lastReportedPos1 = encoderPos1;
    lastReportedPos2 = encoderPos2;
  }
}


void doEncoder1A(void)
{
  A_set1 = digitalRead(encoder1PinA) == HIGH;
  encoderPos1 += (A_set1 != B_set1) ? -1 : +1;
  B_set1 = digitalRead(encoder1PinB) == HIGH;
  encoderPos1 += (A_set1 == B_set1) ? -1 : +1;
}


void doEncoder2A(void)
{
  A_set2 = digitalRead(encoder2PinA) == HIGH;
  encoderPos2 += (A_set2 != B_set2) ? +1 : -1;
  B_set2 = digitalRead(encoder2PinB) == HIGH;
  encoderPos2 += (A_set2 == B_set2) ? +1 : -1;
}


//**********************************************************************************
// Odometry
//**********************************************************************************
void OdomReading(void)
{
  float localencoder1 = encoderPos1;
  float localencoder2 = encoderPos2;
  float deltaEncoder = ((localencoder1 - prevEncoder1) + (localencoder2 - prevEncoder2)) / 2;
  g_odom += ENCODER_TO_1000MM * deltaEncoder / 1000; 
  prevEncoder1 = localencoder1;
  prevEncoder2 = localencoder2;
}


float GetOdom(void)
{
  return g_odom;
}
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

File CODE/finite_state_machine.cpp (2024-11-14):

/************************************
 *        finite_state_machine.cpp       *
 * 
 * Finite state machine only 
 * 
 * Arthors 
 *        Mark   Day
 *        Jack   Wilson
 *        Kieran James
 *************************************/


#include "finite_state_machine.h"
#include "weight_collection.h"
#include "return_to_base.h"
#include "sensors.h"
#include "motors.h"
#include "smartmove.h"
#include "Arduino.h"

//**********************************************************************************
// States 
//**********************************************************************************
enum states {
  START,
  HOME,
  SEARCHING,
  WEIGHTDETECTION,
  WAITFORIR,
  CHECKINDUCTIVE,
  TARGETCOLLECTION,
  DUMMYREJECTION,
  RETURNHOME,
  OPPONENTBASE,
  RAMP,
};
enum states g_CurrentState = START;


//**********************************************************************************
// Program timer
//**********************************************************************************
#define RUN_TIME 1000 * 80
u_int StartTime;


//**********************************************************************************
// Weight Detection and Collection globals 
//**********************************************************************************
#define MAX_WEIGHTS             3
#define TIMER_RETURN_WEIGHT     2
#define DETECTION_TIMEOUT       7000
#define COLLECTION_TIMEOUT      5000
int num_weights = 0;
static unsigned long collection_watchdog = 0;
static unsigned long move_timer = 0;
static unsigned long Detectiontimer;
// Collection Sequence Waits
#define COLLECTION_STAGE_1      50 
#define COLLECTION_STAGE_2      500 + COLLECTION_STAGE_1
#define COLLECTION_STAGE_3      500 + COLLECTION_STAGE_2
#define COLLECTION_STAGE_FINAL  1000 + COLLECTION_STAGE_3
// Rejection Sequence Waits
#define REJECTION_STAGE_1       50 
#define REJECTION_STAGE_2       500 + REJECTION_STAGE_1
#define REJECTION_STAGE_3       1000 + REJECTION_STAGE_2
#define REJECTION_STAGE_FINAL   1000 + REJECTION_STAGE_3

//**********************************************************************************
// Home Globals
//**********************************************************************************
#define NOT_CLOSE_HOME 800
#define LIFTED_ANGLE   4
uint8_t g_playColourflag = 0;

//**********************************************************************************
// Ramp Globals
//**********************************************************************************
#define RAMPANGLE 6
#define RAMPTOFS  200

//**********************************************************************************
// RunStateMachine
//**********************************************************************************
void runStateMachine(void) 
{
  // Special Condictions 
  if (millis() > (RUN_TIME + StartTime) && (num_weights >= TIMER_RETURN_WEIGHT) && (g_CurrentState == SEARCHING)) {
    g_CurrentState = RETURNHOME;
  } 
  if (num_weights == MAX_WEIGHTS) {
    g_CurrentState = RETURNHOME;
    frontGateHalfClose();
  } 
  if (isHome() && g_CurrentState != START){
    g_CurrentState = HOME;
  }
  if (!g_playColourflag && GetDisHome() > NOT_CLOSE_HOME) {
    setPlayColour();
    g_playColourflag = 1;
  } 
  if (!isHome() && !isPlay() && (GetDisHome() > NOT_CLOSE_HOME) && g_playColourflag && (GetAngleofAttack() < LIFTED_ANGLE)) {
    g_CurrentState = OPPONENTBASE;
  }
  if (((GetAngleofAttack() > RAMPANGLE || ((TofbottomLeftValue() < RAMPTOFS) && (TofbottomRightValue() < RAMPTOFS))) 
      && g_CurrentState != START) 
      && GetDisHome() > NOT_CLOSE_HOME){
    g_CurrentState = RAMP;
  }


  // State Machine
  Serial.println(g_CurrentState);
  switch (g_CurrentState) {

    case START: {
    // waits for start button push
      frontGateCentre();
      BackGateClose();
      if (digitalRead(START_BUTTON)) {
        StartTime = millis();
        g_CurrentState = SEARCHING;
      }
      break;
    }


    case SEARCHING: {
    // Main function. Moves unless it sees a weight
      MoveForwardAvoid(10);
      if (get_infrared()) {
        g_CurrentState = CHECKINDUCTIVE;
      } else if (GetWeightDetection()) {
        g_CurrentState = WEIGHTDETECTION;
        Detectiontimer = millis();
      } 
      frontGateCentre();
      BackGateClose();
      break;
    }


    case WEIGHTDETECTION: {
      if (millis() > Detectiontimer + DETECTION_TIMEOUT) {
        Serial.print("Weight Detect timeout");
        g_CurrentState = RAMP;
        return;
      }

      if (GetWeightDetectionLeft()) {
        Serial.println("left");
        if (TofbottomLeftValue() < 200){
          TurnLeftForTime(6, 100);
          collection_watchdog = millis();
          g_CurrentState = WAITFORIR;
        } else if (TofbottomLeftValue() < 400) {
          Serial.println("longturnleft");
          TurnLeftForTime(6, 50);
        }
        MoveForwardAvoid(7);

      } else if (GetWeightDetectionRight()) {
        Serial.println("right");
        if (TofbottomRightValue() < 200){
          TurnRightForTime(6, 100);
          collection_watchdog = millis();
          g_CurrentState = WAITFORIR;
        } else if (TofbottomRightValue() < 400) {
          Serial.println("longturnright");
          TurnRightForTime(6, 50);
        }
        MoveForwardAvoid(7);

      } else if (GetWeightDetectionCenter()) {
        Serial.println("centre");
        MoveForwardAvoid(7);
        if ((TofbottomLeftValue() + TofbottomRightValue())/2 < 300) {
          Serial.println("DRIVE IN");
          collection_watchdog = millis();
          g_CurrentState = WAITFORIR;
        }
      } else {
        g_CurrentState = SEARCHING;
      }
      break;
    }


    case WAITFORIR: {
      // Weight has been seen and robot driving into it.
      if (!get_infrared()) {
        MoveForwardAvoid(7);
        if (millis() > collection_watchdog + COLLECTION_TIMEOUT) {
          Serial.print("Wait IR timeout");
          MoveBackward(10);
          set_motor();
          delay(400);
          TurnLeftForTime(10, 900);
          g_CurrentState = SEARCHING;
          return;
        }

      } else {
        Serial.println("IR DETECTION");
        delay(50);
        MoveForward(0);
        g_CurrentState = CHECKINDUCTIVE;
      }
      break;
    }


    case CHECKINDUCTIVE: {
      delay(100);
      read_inductive();
      move_timer = millis();
      if (get_inductive())
      {
        g_CurrentState = TARGETCOLLECTION;
        Serial.println("Target!");
      } else {
        g_CurrentState = DUMMYREJECTION;
        Serial.println("Dummy!");
      }
      break;
    }
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

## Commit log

2024-11-14 Create cad
2024-11-14 Update and rename motors.cpp to CODE/motors.cpp
2024-11-14 Update and rename motors.h to CODE/motors.h
2024-11-14 Update and rename sensors.cpp to CODE/sensors.cpp
2024-11-14 Update and rename sensors.h to CODE/sensors.h
